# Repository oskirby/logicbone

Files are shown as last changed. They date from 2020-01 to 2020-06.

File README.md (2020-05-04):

LogicBone
=========

When you can't quite find the development board you want, why not make your own?

This project aims to design a feature rich FPGA development board that is
compatible with the open source FPGA synthesis tools such as [yosys](http://www.clifford.at/yosys/),
[NextPNR](https://github.com/YosysHQ/nextpnr) and [SymbiFlow](https://github.com/SymbiFlow),
while also targeting larger logic designs that need faster IO. The
requirements set out for this board are, in order of priority:
 * Compatiblity with open-source FPGA synthesis tools.
 * Minimum of 4Gb of high speed memory, preferably at least 8Gb.
 * At least one Ethernet interface.
 * Compatiblity with existing expansion interfaces.
 * USB interface for programming, debug and power.
 * Licenseable as Open Source Hardware.

The ultimate objective of this board is to instantiate a soft core processor, such as
the RISC-V, and use it to boot a Linux operating system with networking.

To that effect, this board is designed to be mechanically and electrically compatible
with the Beaglebone Black, but featuring a Lattice ECP5 FPGA, which is available in
logic sizes up to 85k LUTs, and a selection of hardware blocks for DDR3 DQS acceleration,
MIPI interfaces, DSPs and 3Gbps SERDES.

Features
--------

The major features of this board include:
 * Lattice ECP5 (LFE5UM5G-45F-8BG381C)
   - 44k LUTs and 351 kbits of distributed RAM 
   - 1944 kbits of embedded block RAM
   - 203 IO pins
   - 72 hardware multipliers
   - 4 PLLs
   - 2 dual channel 5Gbps SERDES
 * Beaglebone Black mechanical and header compatibility.
   - P9 is fully connected to the FPGA.
   - P8 has 32 pins connected to the FPGA.
   - 12-bit 1MSPS muxed ADC on P9 analog pins.
 * 8Gb on-board DDR3L RAM
 * KSZ9031 Gigabit Ethernet PHY
 * microSD card slot
 * USB-C upstream facing port for power and programming
 * USB-C downstream facing port with USB Superspeed support
 * M.2 E-Keyed expansion interface:
   - Accepts connectivity options in the 2230 form factor
   - Both PCIe lanes are routed to the FPGA SERDES
   - GPIO, UART, SDIO and PCM interfaces
 * MaxLinear MxL7704 power manager

Work In Progress
----------------
This project has completed the PCB layout phase, and we are moving into hardware
prototyping. While we wait for the first boards to arrive, we have a 
[schematic](logicbone.pdf) and some renders of the board that might satisfy your
curiosity.

We would be happy to accept any feedback and review on the design that you
might be willing to provide.

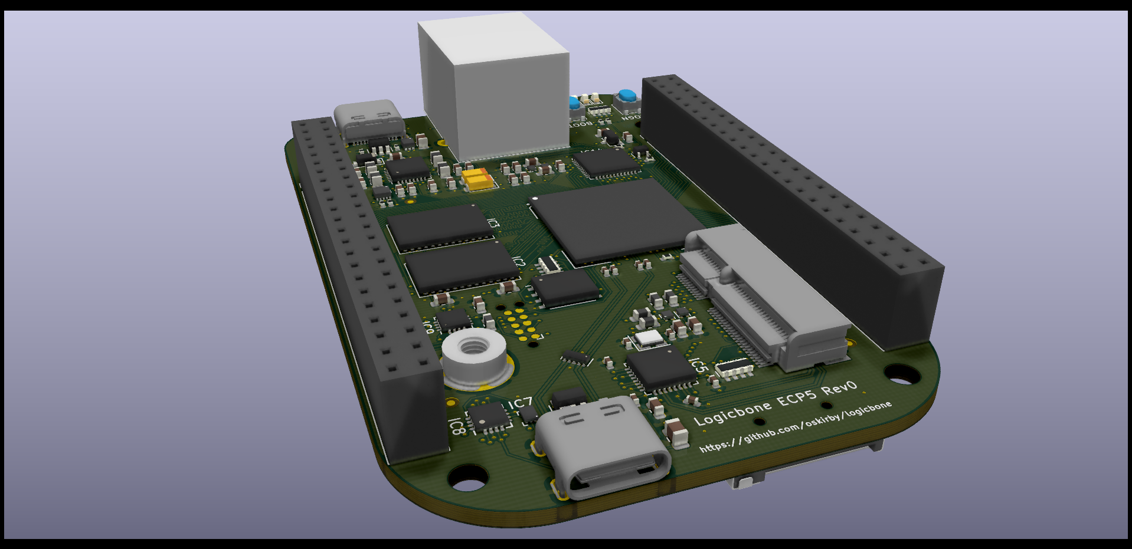
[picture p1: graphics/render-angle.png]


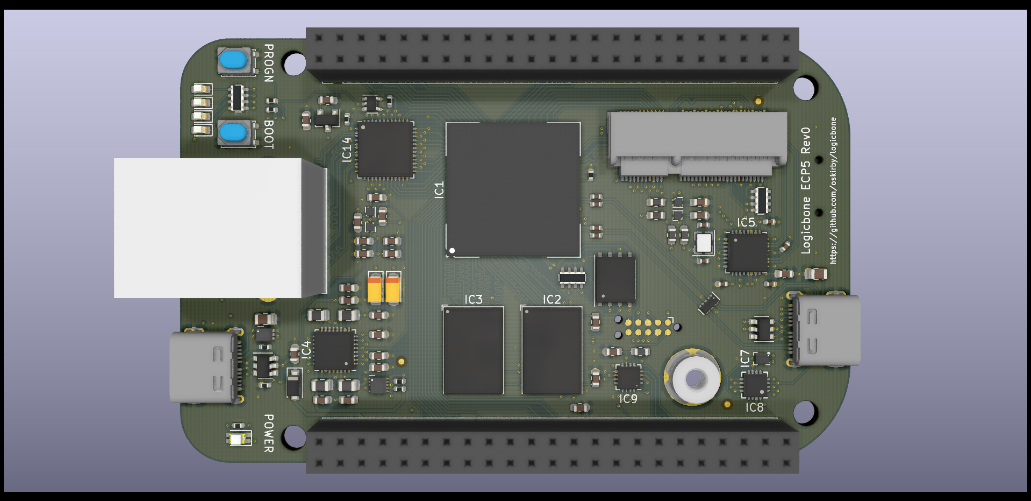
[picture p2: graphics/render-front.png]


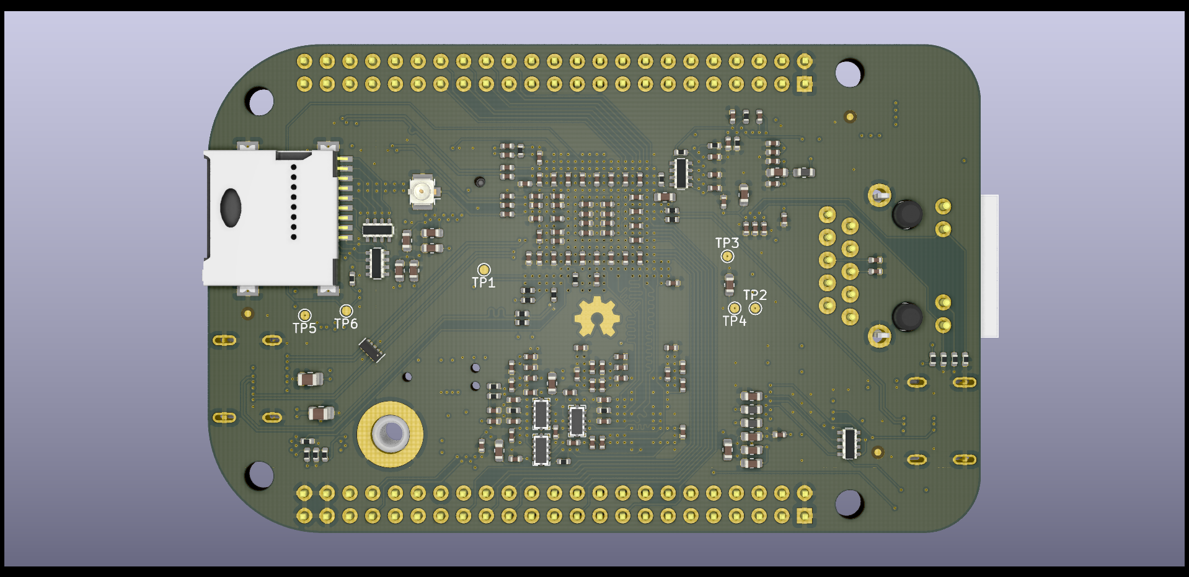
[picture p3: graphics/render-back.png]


Copyright
---------
Copyright Owen Kirby 2020

This documentation describes Open Hardware and is licensed under the
CERN OHL v1.2.

You may redistribute and modify this documentation under the terms of
the CERN OHL v1.2. (see [LICENSE.txt](LICENSE.txt)). This documentation
is distributed WITHOUT ANY EXPRESS OR IMPLIED WARRANTY, INCLUDING OF
MERCHANTABILITY, SATISFACTORY QUALITY AND FITNESS FOR A PARTICULAR
PURPOSE. Please see the CERN OHL v.1.2 for applicable conditions.

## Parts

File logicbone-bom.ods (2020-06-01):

Item | Reference(s) | Value | LibPart | Footprint | MPN Base | MPN Deluxe | Manufacturer | Qty | Order | Price | Total | Price Upg. | Total Upgr. | Link | Datasheet
1 | C101, C102, C103, C105, C106, C107, C110, C111, C112, C113, C114, C115, C116, C118, C120, C121, C122, C123, C124, C200, C201, C210, C211, C220, C221, C230, C231, C251, C257, C260, C261, C264, C265, C266, C280, C300, C301, C302, C309, C310, C311, C316, C317, C318, C319, C401, C402, C403, C411, C412, C413, C421, C422, C423, C431, C432, C433, C451, C452, C454, C455, C456, C461, C462, C463, C464, C465, C467, C469, C500, C501, C502, C503, C512, C522, C532, C542 | 100nF | Device:C_Small | Capacitor_SMD:C_0402_1005Metric | 0402YC104MAT2A |  | AVX Corporation | 77 | 1200 | $0.005 | $0.40 |  | $0.40 | https://www.digikey.com/product-detail/en/avx-corporation/0402YC104MAT2A/478-0402YC104MAT2ACT-ND/11570233 | ~
2 | C104, C117, C150, C151, C152, C153, C154, C155, C156, C157, C158, C159, C160, C161, C162, C163, C164, C165, C166, C167, C168, C169, C170, C250, C255, C303, C304, C308, C315, C400, C410, C420, C430, C440, C441, C442, C443, C445, C460, C533, C543 | 10uF | Device:C_Small | Capacitor_SMD:C_0603_1608Metric | JMK107ABJ106MA-T |  | Taiyo Yuden | 41 | 500 | $0.032 | $1.30 |  | $1.30 | https://www.digikey.com/product-detail/en/taiyo-yuden/JMK107ABJ106MA-T/587-5869-1-ND/7674989 | ~
3 | C108, C109 | 12pF | Device:C_Small | Capacitor_SMD:C_0402_1005Metric | CL05C120JB5NNNC |  | Samsung | 2 | 100 | $0.026 | $0.05 |  | $0.05 | https://www.digikey.com/product-detail/en/samsung-electro-mechanics/CL05C120JB5NNNC/1276-1178-1-ND/3889264 | ~
4 | C119, C125, C126, C127 | 4.7uF/35V | Device:C_Small | Capacitor_SMD:C_0805_2012Metric | CL21A475KLCLQNC |  | Samsung | 4 | 100 | $0.079 | $0.31 |  | $0.31 | https://www.digikey.com/product-detail/en/samsung-electro-mechanics/CL21A475KLCLQNC/1276-6722-1-ND/5961581 | ~
5 | C198, C199 | 47uF | Device:CP | Capacitor_Tantalum_SMD:CP_EIA-3216-10_Kemet-I | DNP | DNP | DNP | 2 |  |  | $0.00 |  | $0.00 |  | ~
6 | C252, C253, C258, C259, C305, C306, C307, C312, C313, C314, C404, C405, C406, C414, C415, C424, C425, C426, C434, C435, C504, C505, C506, C507, C510, C511, C520, C521, C530, C531, C540, C541 | 10nF | Device:C_Small | Capacitor_SMD:C_0402_1005Metric | ‎CL05B103KO5NNNC‎ |  | Samsung | 32 | 500 | $0.007 | $0.21 |  | $0.21 | https://www.digikey.com/product-detail/en/samsung-electro-mechanics/CL05B103KO5NNNC/1276-1051-1-ND/3889137 | ~
7 | D1 | LED_RED_GREEN | Device:LED_Dual_CACA | KiCAD_Magic:LED_0805_DUAL | IN-S85DATRG |  | Inolux | 1 | 15 | $0.291 | $0.29 |  | $0.29 | https://www.mouser.com/ProductDetail/743-IN-S85DATRG | http://www.inolux-corp.com/datasheet/SMDLED/Bi-Color%20Top%20View/IN-S85DATRG_V1.0.pdf
8 | D2, D3, D4, D5 | LED_ALT | Device:LED_ALT | LED_SMD:LED_0603_1608Metric | SML-D13M8WT86 |  | Rohm Semiconductor | 4 | 50 | $0.193 | $0.77 |  | $0.77 | https://www.mouser.com/ProductDetail/755-SML-D13M8WT86 | https://d1d2qsbl8m0m72.cloudfront.net/en/products/databook/datasheet/opto/led/chip_mono/sml-d12x8_d13x8-e.pdf
9 | D6 | SS24FL | Device:D_Schottky_ALT | Diode_SMD:D_SOD-123F | SS24FL |  | ON Semiconductor | 1 | 15 | $0.209 | $0.21 |  | $0.21 | https://www.mouser.com/ProductDetail/512-SS24FL | https://www.onsemi.com/pub/Collateral/SS26FL-D.PDF
10 | D7, D8 | D5V0F4U6SO | Logicbone:D5V0F4U6SO | Package_TO_SOT_SMD:SOT-23-6 | D5V0F4U6SO-7 |  | Diodes Incorporated | 2 | 25 | $0.264 | $0.53 |  | $0.53 | https://www.digikey.com/product-detail/en/diodes-incorporated/D5V0F4U6SO-7/D5V0F4U6SO-7DICT-ND/4457883
11 | D9, D10 | TPD4E02B04 | Logicbone:TPD4E02B04 | Package_SON:USON-10_2.5x1.0mm_P0.5mm | TPD4E02B04DQAR |  | Texas Instruments | 2 | 25 | $0.465 | $0.93 |  | $0.93 | https://www.mouser.com/ProductDetail/595-TPD4E02B04DQAR | http://www.ti.com/lit/ds/symlink/tpd4e02b04.pdf
12 | FB1, FB2, FB3, FB4, FB5, FB7, FB8, FB9 | MPZ1608S600 | Device:Ferrite_Bead_Small | Inductor_SMD:L_0603_1608Metric | MPZ1608S600ATDH5 |  | TDK | 8 | 100 | $0.039 | $0.31 |  | $0.31 | https://www.mouser.com/ProductDetail/810-MPZ1608S600ATDH5 | ~
13 | FID1, FID2, FID3, FID4, FID5, FID6 | Fiducial | Mechanical:Fiducial | Fiducial:Fiducial_0.75mm_Mask1.5mm | DNP | DNP | DNP | 6 |  |  | $0.00 |  | $0.00 |  | ~
14 | H1, H2, H3, H4 | MountingHole | Mechanical:MountingHole | MountingHole:MountingHole_3.2mm_M3 | DNP | DNP | DNP | 4 |  |  | $0.00 |  | $0.00 |  | ~
15 | H5 | 9774025360 | Mechanical:MountingHole_Pad | Logicbone:wurth-9774025360 | 9774025360R |  | Wurth | 1 | 15 | $0.907 | $0.91 |  | $0.91 | https://www.mouser.com/ProductDetail/710-9774025360R | https://www.mouser.com/datasheet/2/445/9774025360R-1728785.pdf
16 | IC1 | ECP5UM-CABGA381 | Logicbone:ECP5UM-CABGA381 | Logicbone:caBGA-381_20x20_17.0x17.0mm | LFE5UM5G-45F-8BG381C | LFE5UM5G-85F-8BG381C | Lattice Semiconductor | 1 | 12 | $31.260 | $31.26 | $54.890 | $54.89 | https://www.digikey.com/product-detail/en/lattice-semiconductor-corporation/LFE5UM5G-45F-8BG381C/220-2107-ND/6173744
17 | IC2, IC3 | DDR3-TFBGA78 | KiCAD-Magic:DDR3-TFBGA78 | Package_BGA:FBGA-78_7.5x11mm_Layout2x3x13_P0.8mm | MT41K512M8DA-107:P | AS4C1G8MD3L-12BCN | Micron | 2 | 24 | $6.409 | $12.82 | $21.082 | $42.16 | https://www.digikey.com/product-detail/en/micron-technology-inc/MT41K512M8DA-107-P/557-1764-ND/5956624 | https://www.mouser.ca/datasheet/2/671/4Gb_DDR3L-1283964.pdf
18 | IC4 | MXL7704 | Logicbone:MXL7704 | Package_DFN_QFN:QFN-32-1EP_5x5mm_P0.5mm_EP3.65x3.65mm | MxL7704-AQB-R |  | MaxLinear | 1 | 12 | $4.058 | $4.06 |  | $4.06 | https://www.digikey.com/product-detail/en/maxlinear-inc/MXL7704-AQB-R/1016-2220-1-ND/10322951 | https://www.maxlinear.com/ds/mxl7704.pdf
19 | IC5 | PI6CG18401 | Logicbone:PI6CG18401 | Package_DFN_QFN:QFN-32-1EP_5x5mm_P0.5mm_EP3.1x3.1mm | PI6CG18401ZHIEX |  | Diodes Incorporated | 1 | 12 | $2.590 | $2.59 |  | $2.59 | https://www.mouser.com/ProductDetail/729-PI6CG18401ZHIEX
20 | IC6 | NCP349 | Logicbone:NCP349 | Logicbone:DFN6_1.6x2mm | NCP349MNBK |  | ON Semiconductor | 1 | 15 | $0.682 | $0.68 |  | $0.68 | https://www.mouser.com/ProductDetail/863-NCP349MNBKTBG
21 | IC7 | FPF2595 | Logicbone:FPF2595 | Logicbone:WLCSP-12_3x4_1.3x1.8mm | FPF2595UCX |  | ON Semiconductor | 1 | 15 | $0.783 | $0.78 |  | $0.78 | https://www.mouser.com/ProductDetail/512-FPF2595UCX | https://www.onsemi.com/pub/Collateral/FPF2595-D.pdf
22 | IC8 | FUSB307 | Logicbone:FUSB307 | Package_DFN_QFN:UQFN-16-1EP_3x3mm_P0.5mm_EP1.75x1.75mm | FUSB307BMPX |  | ON Semiconductor | 1 | 15 | $1.020 | $1.02 |  | $1.02 | https://www.mouser.com/ProductDetail/863-FUSB307BMPX | https://www.onsemi.com/pub/Collateral/FUSB307B-D.PDF
23 | IC9 | TLA2518 | Logicbone:TLA2518 | Package_DFN_QFN:WQFN-16-1EP_3x3mm_P0.5mm_EP1.75x1.75mm | TLA2518IRTER |  | Texas Instruments | 1 | 12 | $3.142 | $3.14 |  | $3.14 | https://www.digikey.com/product-detail/en/texas-instruments/TLA2518IRTER/296-TLA2518IRTERCT-ND/11502569 | http://www.ti.com/lit/ds/symlink/tla2518.pdf
24 | IC10 | W25Q128 | Memory_Flash:AT25SF081-XMHF-X | Package_DFN_QFN:DFN-8-1EP_6x5mm_P1.27mm_EP4x4mm | W25Q128JVPIQ |  | Winbond | 1 | 12 | $1.342 | $1.34 |  | $1.34 | https://www.digikey.com/product-detail/en/winbond-electronics/W25Q128JVPIQ/W25Q128JVPIQ-ND/6819668 | https://www.winbond.com/resource-files/w25q128jv%20revf%2003272018%20plus.pdf
25 | IC12 | 74LVC1G07 | Logicbone:74AUC1G07 | Package_TO_SOT_SMD:SOT-353_SC-70-5 | 74LVC1G07GW,125 |  | Nexperia | 1 | 15 | $0.141 | $0.14 |  | $0.14 | https://www.mouser.com/ProductDetail/771-74LVC1G07GW-G | https://assets.nexperia.com/documents/data-sheet/74LVC1G07.pdf
26 | IC13 | TPS51206 | Logicbone:TPS51206 | Logicbone:WSON-10EP-2x2mm | TPS51206DSQR |  | Texas Instruments | 1 | 15 | $0.683 | $0.68 |  | $0.68 | https://www.mouser.com/ProductDetail/595-TPS51206DSQR | http://www.ti.com/lit/ds/symlink/tps51206.pdf
27 | IC14 | KSZ9031RNXCC | Interface_Ethernet:KSZ9031RNXCA | Package_DFN_QFN:QFN-48-1EP_7x7mm_P0.5mm_EP5.15x5.15mm | KSZ9031RNXCC |  | Microchip | 1 | 12 | $2.810 | $2.81 |  | $2.81 | https://www.digikey.com/product-detail/en/microchip-technology/KSZ9031RNXCC-TR/KSZ9031RNXCC-CT-ND/7917225 | http://ww1.microchip.com/downloads/en/DeviceDoc/00002117C.pdf
28 | IC17, IC18 | NCP110AMX110 | Logicbone:NCP110 | Package_DFN_QFN:UDFN-4-1EP_1x1mm_P0.65mm_EP0.48x0.48mm | NCP110AMX120TBG |  | ON Semiconductor | 2 | 25 | $0.270 | $0.54 |  | $0.54 | https://www.mouser.com/ProductDetail/863-NCP110AMX120TBG | https://www.onsemi.com/pub/Collateral/NCP110-D.PDF
29 | IC19, IC20 | NCP115AMX250 | Logicbone:NCP110 | Package_DFN_QFN:UDFN-4-1EP_1x1mm_P0.65mm_EP0.48x0.48mm | NCP115AMX250TCG |  | ON Semiconductor | 2 | 25 | $0.197 | $0.39 |  | $0.39 | https://www.mouser.com/ProductDetail/863-NCP115AMX250TCG | https://www.onsemi.com/pub/Collateral/NCP115-D.PDF
30 | J1 | NGFF-KEY-E | Logicbone:NGFF-KEY-E | Logicbone:TE-2199230-4 | 2199230-4 |  | TE Connectivity | 1 | 15 | $1.010 | $1.01 |  | $1.01 | https://www.mouser.com/ProductDetail/571-2199230-4
31 | J2, J5 | USB_C_Receptacle | Connector:USB_C_Receptacle | Logicbone:Molex-1054500101 | 1054500101 |  | Molex | 2 | 25 | $1.949 | $3.90 |  | $3.90 | https://www.digikey.com/product-detail/en/molex/1054500101/WM12856CT-ND/5843891 | https://www.usb.org/sites/default/files/documents/usb_type-c.zip
32 | J3 | ARJM11xx-502 | Logicbone:ARJM11xx-502 | Logicbone:ARJM11B1_502 | ARJM11B1-502-AB-ER2-T |  | Abracon | 1 | 12 | $4.752 | $4.75 |  | $4.75 | https://www.digikey.com/product-detail/en/abracon-llc/ARJM11B1-502-AB-ER2-T/535-14133-1-ND/7675242
33 | J4 | TC2050-IDC-NL | Connector_Generic:Conn_02x05_Odd_Even | Connector:Tag-Connect_TC2050-IDC-NL_2x05_P1.27mm_Vertical | TC2050-IDC-NL |  | Tag Connect | 1 |  | $0.000 | $0.00 |  | $0.00 |  | ~
34 | J6 | Micro_SD_MEM2075 | Logicbone:Micro_SD_MEM2075 | Logicbone:MEM2075 | MEM2075-00-140-01-A |  | GCT | 1 | 12 | $1.860 | $1.86 |  | $1.86 | https://www.digikey.com/product-detail/en/gct/MEM2075-00-140-01-A/2073-MEM2075-00-140-01-ACT-ND/9859685 | https://gct.co/files/drawings/mem2075.pdf
35 | J7 | u.FL | Connector:Conn_Coaxial | Connector_Coaxial:U.FL_Hirose_U.FL-R-SMT-1_Vertical | DNP | DNP | DNP | 1 |  |  | $0.00 |  | $0.00 |  | ~
36 | L1 | 2.2uH | Device:L | Inductor_SMD:L_0805_2012Metric | TFM201610ALM-2R2MTAA |  | TDK | 1 | 15 | $0.374 | $0.37 |  | $0.37 | https://www.mouser.com/ProductDetail/810-TFM2161ALM2R2MTA | ~
37 | L2, L4 | 0.47uH | Device:L | Inductor_SMD:L_0805_2012Metric | TFM201610ALM-R47MTAA |  | TDK | 2 | 25 | $0.374 | $0.75 |  | $0.75 | https://www.mouser.com/ProductDetail/810-TFM2161ALMR47MTA | https://product.tdk.com/info/en/catalog/datasheets/inductor_commercial_power_tfm201610alm_en.pdf
38 | L3 | 1uH | Device:L | Inductor_SMD:L_0805_2012Metric | MAKK2016T1R0M |  | Taiyo Yuden | 1 | 15 | $0.180 | $0.18 |  | $0.18 | https://www.mouser.com/ProductDetail/963-MAKK2016T1R0M | ~
39 | P8, P9 | BB_2x23 | Connector_Generic:Conn_02x23_Odd_Even | Connector_PinHeader_2.54mm:PinHeader_2x23_P2.54mm_Vertical | PPPC232LFBN-RC |  | Sullins Connector | 2 | 25 | $2.333 | $4.67 |  | $4.67 | https://www.digikey.com/product-detail/en/sullins-connector-solutions/PPPC232LFBN-RC/S7126-ND/810262 | ~
40 | Q1 | Q_PMOS_GSD | Device:Q_PMOS_GSD | Package_TO_SOT_SMD:SOT-23 | FDV304P |  | ON Semiconductor | 1 | 15 | $0.200 | $0.20 |  | $0.20 | https://www.mouser.com/ProductDetail/512-FDV304P | https://www.onsemi.com/pub/Collateral/FDV304P-D.PDF
41 | R1, R2, R6, R37 | 33 | Device:R | Resistor_SMD:R_0402_1005Metric | ERJ-2RKF33R0X |  | Panasonic | 4 | 100 | $0.201 | $0.80 |  | $0.80 | https://www.digikey.com/product-detail/en/panasonic-electronic-components/ERJ-2RKF33R0X/P33-0LCT-ND/1746675 | ~
42 | R3, R4, R10, R27, R28 | 240 | Device:R | Resistor_SMD:R_0402_1005Metric | ERJ-2RKF2400X |  | Panasonic | 5 | 100 | $0.021 | $0.11 |  | $0.11 | https://www.mouser.com/ProductDetail/667-ERJ-2RKF2400X | ~
43 | R5, R39 | 100 | Device:R_Small | Resistor_SMD:R_0402_1005Metric | ERJ-2RKF1000X |  | Panasonic | 2 | 100 | $0.017 | $0.03 |  | $0.03 | https://www.mouser.com/ProductDetail/667-ERJ-2RKF1000X | ~
44 | R7 | 12.1k | Device:R_Small | Resistor_SMD:R_0402_1005Metric | ERJ-2RKF1212X |  | Panasonic | 1 | 100 | $0.015 | $0.02 |  | $0.02 | https://www.mouser.com/ProductDetail/667-ERJ-2RKF1212X | ~
46 | R11, R12, R18, R32 | 5.1k | Device:R | Resistor_SMD:R_0402_1005Metric | ERJ-2RKF5101X |  | Panasonic | 4 | 100 | $0.017 | $0.07 |  | $0.07 | https://www.mouser.com/ProductDetail/667-ERJ-2RKF5101X | ~
47 | R8, R13, R19, R20, R21, R22, R23, R24, R25, R29, R30, R31, R35 | 10k | Device:R | Resistor_SMD:R_0402_1005Metric | ERJ-2RKF1002X |  | Panasonic | 13 | 200 | $0.016 | $0.21 |  | $0.21 | https://www.mouser.com/ProductDetail/667-ERJ-2RKF1002X | ~
48 | R14, R15, R16, R38 | 47 | Device:R | Resistor_SMD:R_0402_1005Metric | ERJ-2RKF47R0X |  | Panasonic | 4 | 100 | $0.017 | $0.07 |  | $0.07 | https://www.mouser.com/ProductDetail/667-ERJ-2RKF47R0X | ~
49 | R17, R26 | 1.5k | Device:R | Resistor_SMD:R_0402_1005Metric | ERJ-2RKF1501X |  | Panasonic | 2 | 100 | $0.006 | $0.01 |  | $0.01 | https://www.digikey.com/product-detail/en/panasonic-electronic-components/ERJ-2RKF1501X/P1-50KLCT-ND/194105 | ~
50 | R33 | 750 | Device:R | Resistor_SMD:R_0402_1005Metric | ERJ-2RKF7500X |  | Panasonic | 1 | 100 | $0.018 | $0.02 |  | $0.02 | https://www.mouser.com/ProductDetail/667-ERJ-2RKF7500X | ~
51 | R34, R36 | 1.2k | Device:R | Resistor_SMD:R_0402_1005Metric | ERJ-2RKF1201X |  | Panasonic | 2 | 100 | $0.016 | $0.03 |  | $0.03 | https://www.mouser.com/ProductDetail/667-ERJ-2RKF1201X | ~
53 | RN1, RN2, RN3 | 47 | Device:R_Network08 | KiCAD_Magic:EXBD-1206 | EXB-D10C470J |  | Panasonic | 3 | 100 | $0.163 | $0.49 |  | $0.49 | https://www.mouser.com/ProductDetail/667-EXB-D10C470J | http://www.vishay.com/docs/31509/csc.pdf
54 | RN4, RN5, RN6, RN7, RN8, RN11 | 10k | Device:R_Pack04 | Resistor_SMD:R_Array_Concave_4x0603 | CAT16-103J4GLF |  | Bourns | 6 | 100 | $0.014 | $0.08 |  | $0.08 | https://www.mouser.com/ProductDetail/652-CAT16-103J4GLF | ~
55 | RN9 | 470 | Device:R_Pack04 | Resistor_SMD:R_Array_Concave_4x0603 | CAT16-471J4LF |  | Bourns | 1 | 100 | $0.092 | $0.09 |  | $0.09 | https://www.mouser.com/ProductDetail/652-CAT16-471J4LF | ~
56 | SW1, SW2 | SW_SPST | Switch:SW_SPST | Button_Switch_SMD:SW_SPST_PTS810 | PTS810 SJK 250 SMTR LFS |  | C&K Switches | 2 | 25 | $0.165 | $0.33 |  | $0.33 | https://www.mouser.com/ProductDetail/611-PTS810SJK250SMTR | https://dznh3ojzb2azq.cloudfront.net/products/Tactile/PTS810/documents/datasheet.pdf
57 | Y1 | 25MHz | Logicbone:Crystal_GND24 | Crystal:Crystal_SMD_2520-4Pin_2.5x2.0mm | ECS-250-18-36B-CKY-TR |  | ECS Inc. | 1 | 15 | $0.363 | $0.36 |  | $0.36 | https://www.mouser.com/ProductDetail/520-250-18-36B-CKYT | https://ecsxtal.com/store/pdf/ECX-2236B.pdf
 |  |  |  |  |  |  |  |  |  | Total: | $88.90 | Total Upgr: | $141.87

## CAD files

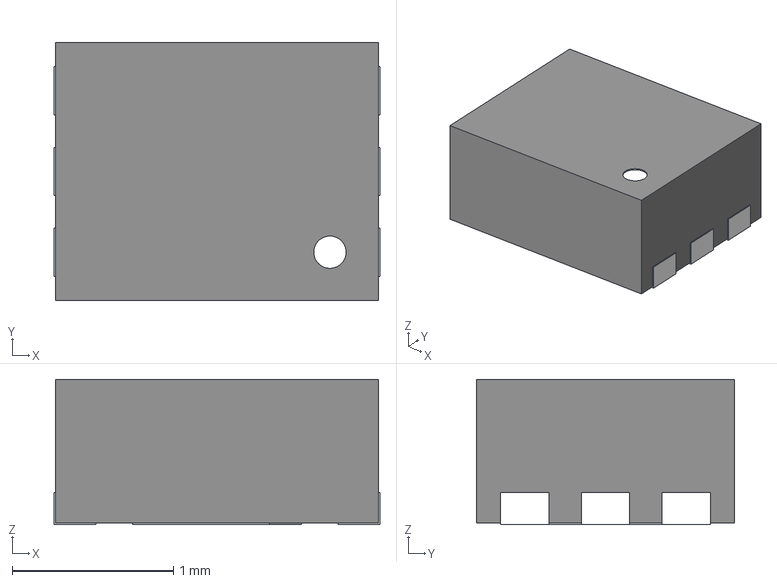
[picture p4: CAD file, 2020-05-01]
package3d/dfn6-2x1.6mm.step
2.02 x 1.60 x 0.9 mm

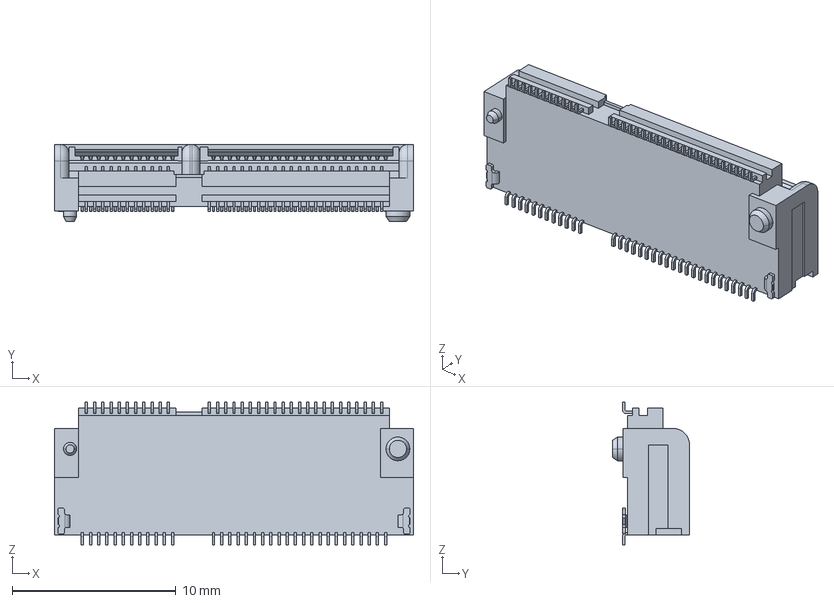
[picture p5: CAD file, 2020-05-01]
package3d/c-2199230-4-b2-3d.stp
21.9 x 4.70 x 8.70 mm

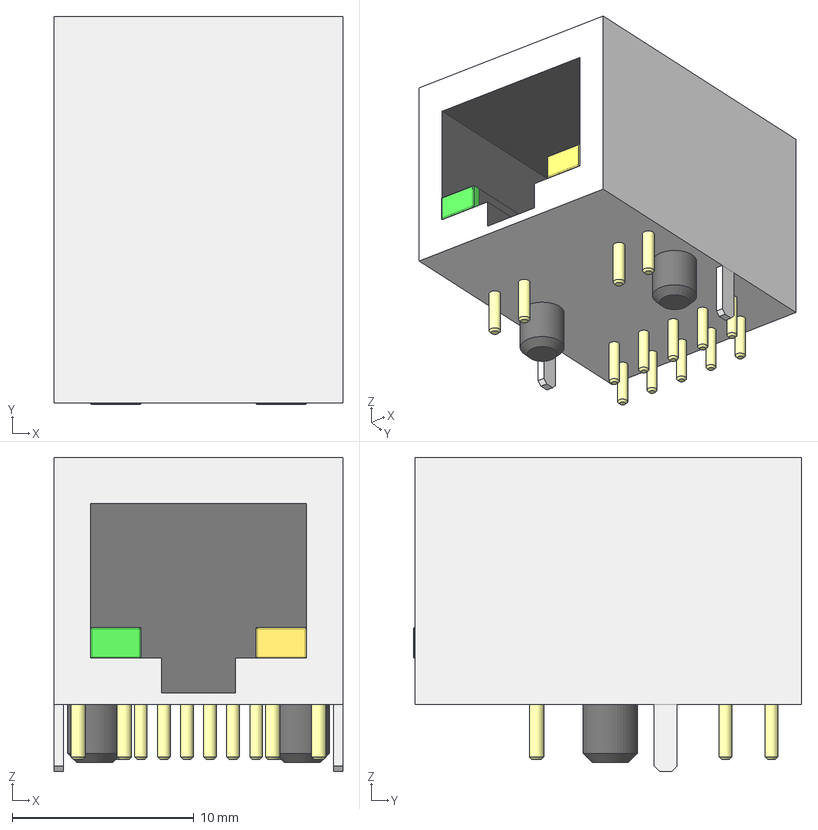
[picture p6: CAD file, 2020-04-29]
package3d/arjm11b1-502.step
15.9 x 21.4 x 17.3 mm

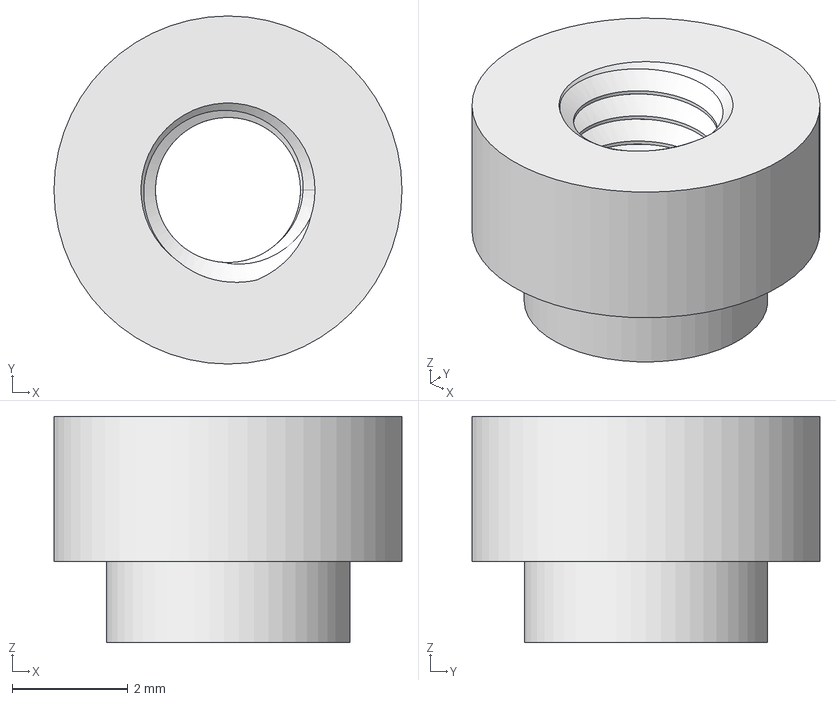
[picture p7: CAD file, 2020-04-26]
package3d/wurth-9774025360.step
6.00 x 6.00 x 3.90 mm

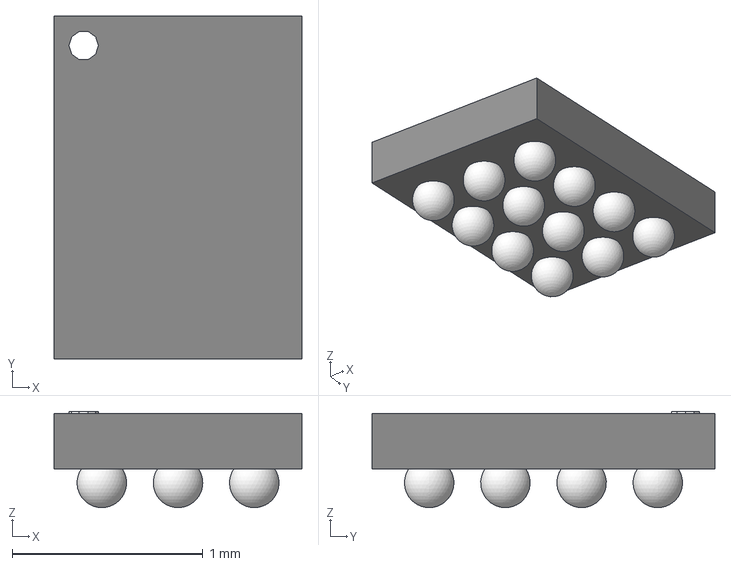
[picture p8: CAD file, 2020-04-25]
package3d/wlcsp12-p04mm.step
1.30 x 1.80 x 0.505 mm

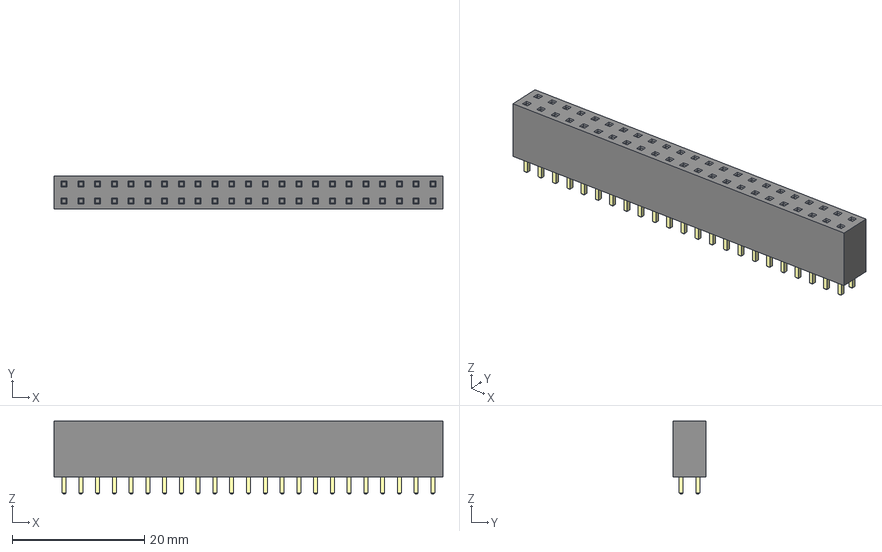
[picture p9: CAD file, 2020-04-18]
package3d/bb-pin-header-2x23.step
58.9 x 5.00 x 11.1 mm

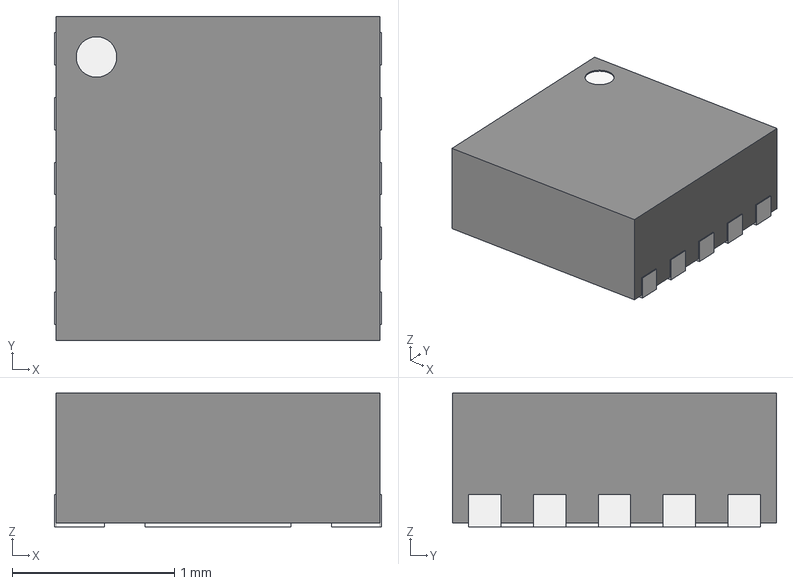
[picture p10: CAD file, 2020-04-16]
package3d/WSON10-2x2mm-EP.step
2.02 x 2.00 x 0.825 mm

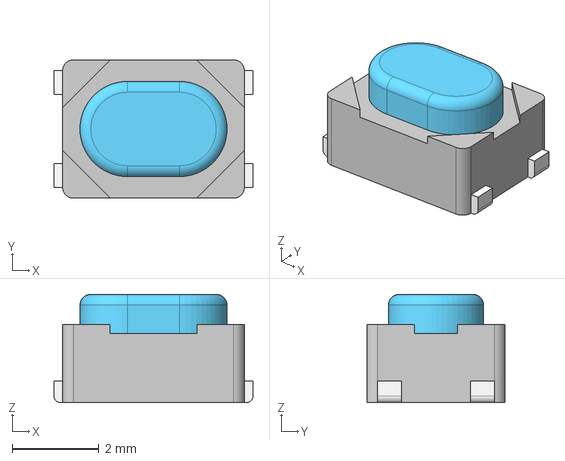
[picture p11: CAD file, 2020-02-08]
package3d/PTS810.step
4.60 x 3.20 x 2.50 mm

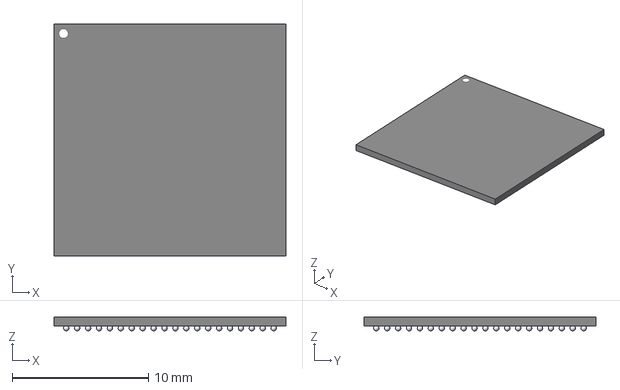
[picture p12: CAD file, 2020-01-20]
package3d/cabga-381-ecp5.step
17.0 x 17.0 x 1.01 mm

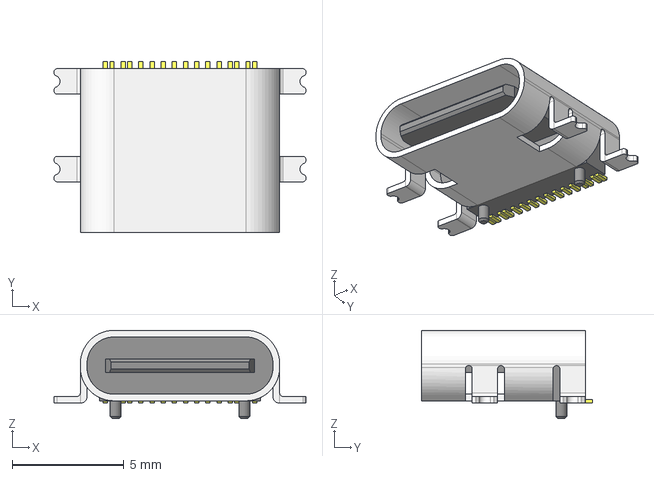
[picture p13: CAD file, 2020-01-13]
package3d/usb4110.step
11.3 x 7.68 x 3.96 mm

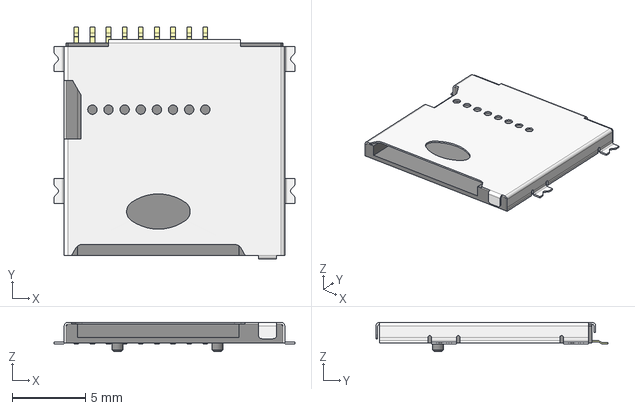
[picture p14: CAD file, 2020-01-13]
package3d/microsd-mem2075.step
16.4 x 15.8 x 2.00 mm

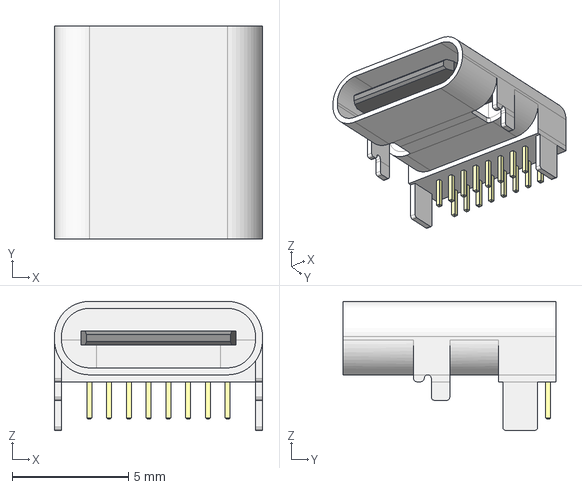
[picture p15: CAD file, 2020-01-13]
package3d/usb4085.step
8.95 x 9.17 x 5.56 mm

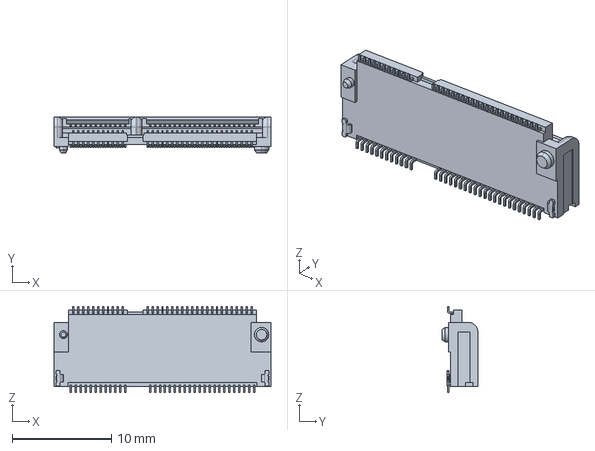
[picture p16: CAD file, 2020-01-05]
package3d/c-2199119-4-c-3d.stp
21.9 x 3.62 x 8.70 mm

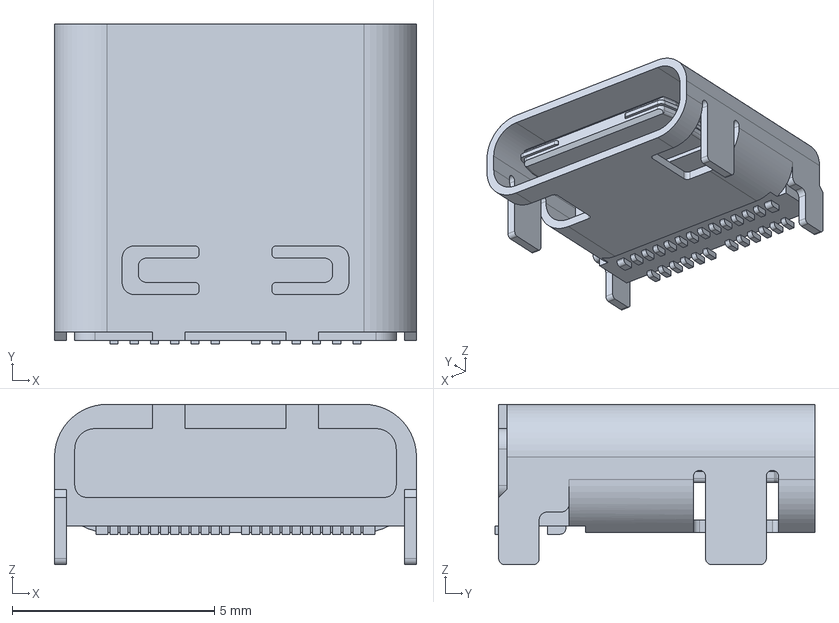
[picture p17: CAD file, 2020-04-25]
package3d/1054500101.stp
8.94 x 7.90 x 3.96 mm

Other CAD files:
package3d/arjm11b1-502.fcstd
package3d/bb-pin-header-2x23.FCStd
package3d/microsd-mem2075.fcstd
package3d/usb4085.fcstd
package3d/usb4110.fcstd

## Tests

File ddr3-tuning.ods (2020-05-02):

 | Inner Speed | Outer Speed
 | 6.7972 | 5.54599 | ps/mm
Net | Inner1 | Outer1 | Time1 | Error1 | Inner2 | Outer2 | Time2 | Error2
DDR3_CLK | 22.043 | 0 | 149.8306796 | 0 | 10.494 | 0 | 221.1604964 | 0
DDR3_A0 | 20.581 | 0 | 139.8931732 | -9.93750639999999 | 10.765 | 0 | 213.0650312 | -8.09546519999998
DDR3_A1 | 19.318 | 0 | 131.3083096 | -18.52237 | 10.197 | 0.8 | 205.05615 | -16.1043464
DDR3_A2 | 19.318 | 0 | 131.3083096 | -18.52237 | 11.57 | 1.6 | 218.8254976 | -2.33499879999999
DDR3_A3 | 22.145 | 0 | 150.523994 | 0.693314399999991 | 0 | 10.197 | 207.07645403 | -14.08404237
DDR3_A4 | 21.718 | 0 | 147.6215896 | -2.20909 | 12.577 | 0 | 233.109974 | 11.9494776
DDR3_A5 | 22.347 | 0 | 151.8970284 | 2.06634880000001 | 12.696 | 0 | 238.1942796 | 17.0337832
DDR3_A6 | 0 | 25.003 | 138.66638797 | -11.16429163 | 9.963 | 0 | 206.38689157 | -14.77360483
DDR3_A7 | 22.625 | 0 | 153.78665 | 3.95597040000001 | 0 | 12.694 | 224.18744706 | 3.02695066000001
DDR3_A8 | 24.333 | 0 | 165.3962676 | 15.565588 | 0 | 11.386 | 228.54290974 | 7.38241333999997
DDR3_A9 | 23.533 | 0 | 159.9585076 | 10.127828 | 11.04 | 0 | 234.9995956 | 13.8390992
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

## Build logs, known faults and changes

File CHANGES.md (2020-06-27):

# Logicbone ECP5 Changelog

All notable changes to the project will be documented in this file.

## Logicbone - Unreleased Changes
 - Annotated schematic with required bodges for board bringup.

## Logicbone - rev0-prototype - 2020-06-01
 - Initial release of rev0 prototype design.

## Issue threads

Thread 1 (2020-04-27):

Validate ECP5 pinout

oskirby, 2020-04-27:
The caBGA381 is a big package, with a lot of balls. That's a lot of data entry that is ripe for user error and we should take some time to review the pinout to make sure its correct before manufacturing begins.

We also need to pay attention to compatibility between logic sizes, and the ECP5-5G variants to get an idea of which parts can be substituted.

oskirby, 2020-04-30:
It seems that the ECP5 and ECP5-5G versions are interchangeable with one another, with a few tweaks to voltage programming (1.2V core and SERDES instead of 1.1V).

On the 45F logic sizes, pads K16 and K17 are no-connect, and fortunately we are not using them for anything on this design (they were sacrificed to make room for more bypass caps).

TLDR: This design is compatible with both the ECP5 and ECP5-5G in either the 45F or 85F logic sizes.

Closed 2020-04-29.

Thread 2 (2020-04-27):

Create BOM

oskirby, 2020-04-27:
Chase down supplier links for everything on the board to make sure nothing has magically gone out of stock and to get some estimates on pricing.

oskirby, 2020-05-03:
Closed in commit b731f665e2e0ec511eb55cc5416a246310af917d

There are three possible variants of builds that I am considering, depending on how much memory and logic are available. For the prototype run, I only plan on building the base and deluxe versions.

FPGA                  | Memory | Price Change | Description
-----------------------|-------------|--------------------|---------------
LFE5UM-45F      | 512MB   |                        | Base model
LFE5UM5G-45F | 1GB       |  +10$              | USBSS and PCIe 2.0 capable
LFE5UM5G-85F | 2GB       | +60$               | Deluxe model

oskirby, 2020-05-04:
After thinking about it a bit more, it seems silly not to just use the ECP5-5G for all builds, it only adds about $5 when compared to the non-5G part in the same logic size. I have gone and tweaked the BOM accordingly to make the LFE5UM5G-45F and 1GB of DDR3 as the base model.

See: 2c916801f092d31ea59eb32323762b132f2a3a1c

Closed 2020-05-03.

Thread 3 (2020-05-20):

Bad part choices (prototype run)

oskirby, 2020-05-20:
This issue is mostly just to keep a list of parts that we might want to change out if we get a chance.

| Designators | Part                 |  Issue
|------------------|--------------------|----------
| IC7 | FPF2595         | 0.4mm pitch CSP package is a little too fine. Our stencil manufacturer has raised concerns about yield.
| L4, L2 | 0805 Inductor | High current inductors for VCORE and VDDR are a little hard to source in this size. Suggest using a larger footprint to increase options and reduce cost.
| RN1, RN2, RN3 | EXB-D10C470J | Panasonic seems to be the only vendor for this particular footprint, which might lead to supply issues for future production runs. The 2x5 pin rectangular arrangement seems to be more common.

oskirby, 2020-06-04:
Another comment from the CM is that the XDFN regulators are a pain in the butt, and should be substituted with a larger and less ambiguous part (such as a TSOP-5).

oskirby, 2020-06-19:
While we're at it, the PGOOD LED (D1) is way too bright and we should increase its inline resistance (R10). To avoid adding another line item to the BOM, the next value of resistance to try would be 750 ohm.

oskirby, 2020-06-20:
After a quick bodge, it seems that 750ohm leave the green LED in D1 too bright,  but the red LED is about right. I think the whole circuit around D1 should be rethought either into discrete LEDs, or to add another resistor tune the drive strength of red and green separately.

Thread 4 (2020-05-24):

P8 eMMC pinouts are incorrect

oskirby, 2020-05-24:
It seems that there is an discrepancy in the Beaglebone Black reference manual, and the schematic. The SRM states that P8 pins 11 through 21 are used for the eMMC and shouldn't be used by the capes when the eMMC is in use, but the Beaglebone schematics show P8 pins 3-6 and 20-25 are used by the eMMC.

Unfortunately, the Logicbone was laid out according to the reference manual, which means that we won't be compatible with capes that make use of P8 pins 11-21 such as the CRAMPS board or 24-bit LCD displays.

oskirby, 2020-05-24:
For the record, I was working with the BBB_SRM revision A5.2 dated April 11th, 2013

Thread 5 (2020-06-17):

PMIC 5VSYS pin is a power input (not output)

oskirby, 2020-06-17:
The MxL7704 datasheet leaves the purpose of the 5VSYS pin a bit ambiguous as to whether it is internally connected to VIN, or whether it's requires an external RC filter to VIN. Turns out it needs an external RC filter. We can work around it on the prototypes by bodging a 10ohm resistor between 5VSYS and VBUS, but this should be fixed for future production runs.

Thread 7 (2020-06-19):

ECP5 has no means to reset itself

oskirby, 2020-06-19:
It seems that there are three ways in which the ECP5 can reset itself in order to handle multi-boot images:
- VCC, VCCAUX and VCCIO8 rise above their POR thresholds.
- Rising edge on PROGRAMN pin
- Issuing a REFRESH command over SPI slave or JTAG ports.

I was hoping that one of the config ports would have been accessible internally from the FPGA fabric to issue the REFRESH command, but this doesn't appear to be the case so instead we'll need to bodge the board so that the FPGA can pull the PROGRAMN pin.

On the prototypes, we will work around the issue by removing IC12 and bridging ETH_RESET to SYS_RESET. This will allow the ETH_RESET pin to reboot the FPGA, but we loose the ability to reset the ethernet PHY independently of the rest of the system.

A better solution would be to pull SYS_RESET low via one of the unused pins in the DDR3 bank.

oskirby, 2020-07-26:
For the DFU bootloader, it has been requested to add some non-volatile state that can allow the user image to boot into the DFU image without needing to physically press the boot pin. Without such a state, the DFU bootloader has no way to distinguish between a normal power-on and when rebooting back into the DFU bootloader.

oskirby, 2020-07-27:
I think my favourite solution so far to the non-volatile "goto DFU" problem is to use a small IO expander such as the PCA9570 to control the pull-up on the boot button. At a true power-on reset, the PCA9570 would initialize to a pull-up state but when pulled low before a soft reset, the bootloader would detect this as a "goto DFU" reboot.

bmentink, 2022-07-13:
Any solution to this?

oskirby, 2022-07-13:
@bmentink for the ECP5 in general, the common solution is to connect the `PROGRAMn` pin to any GPIO of the FPGA, which gives the logic fabric the ability to pull `PROGRAMn` and trigger a reset of the FPGA. This works just fine, but it makes the boot process somewhat inflexible when there are multiple bitstreams to navigate.

For the Logicibone, my prototype board have been modified to reuse the reset line on the ethernet controller to achieve this behavior (this is noted on page 4 of the schematic). A permanent fix will require another board revision to provide a dedicated reset line. I don't have any plans to produce another board revision for the foreseeable future due to the chip shortage and a general lack of time to work on this project.

bmentink, 2022-07-13:
@oskirby
Many thanks for the reply. I was asking as I am trying to port your bootloader to the Colorlight i5 board as per:
[((https://github.com/oskirby/tinydfu-bootloader/issues/5))]

With the resetn GPIO line connected to PROGRAMN, how do you select which image to boot to ... (bootloader or user)?

Cheers,

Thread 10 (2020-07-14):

Finish testing prototype hardware

oskirby, 2020-07-14:
The list of things yet to be tested on the prototype boards before we should start looking into the next revision

- [ ] Micro-SD card slot.
- [ ] Downstream-Facing USB port detection and power management.
- [ ] Downstream-Facing USB port SERDES support (test out https://github.com/enjoy-digital/usb3_pipe)
- [ ] Analog-to-Digital converter.
- [ ] m.2 PCIe SERDES support.
- [ ] Gather noise and current measurements for VCORE and VDDR supplies.
- [ ] LiteX support for 2GB memory size.

oskirby, 2020-07-14:
So far the microSD card seems to work in SPI mode, and I have been to boot from it using the LiteX BIOS. I have thus far been unsuccessful in getting Linux to detect the cards. The full-width microSD card support in Litex still seems like a work in progress.

oskirby, 2020-07-14:
A new commit to the bootloader (https://github.com/oskirby/tinydfu-bootloader/commit/1e0b711ec6c7751dd92b2645906e17b54229aafb) should now enable the DFP port power.

oskirby, 2020-07-19:
I've added a test to verify that the ADC works as expected (https://github.com/oskirby/logicbone-tests/commit/b8254bc7a177077abc939152cf0f3d3648f6a925)

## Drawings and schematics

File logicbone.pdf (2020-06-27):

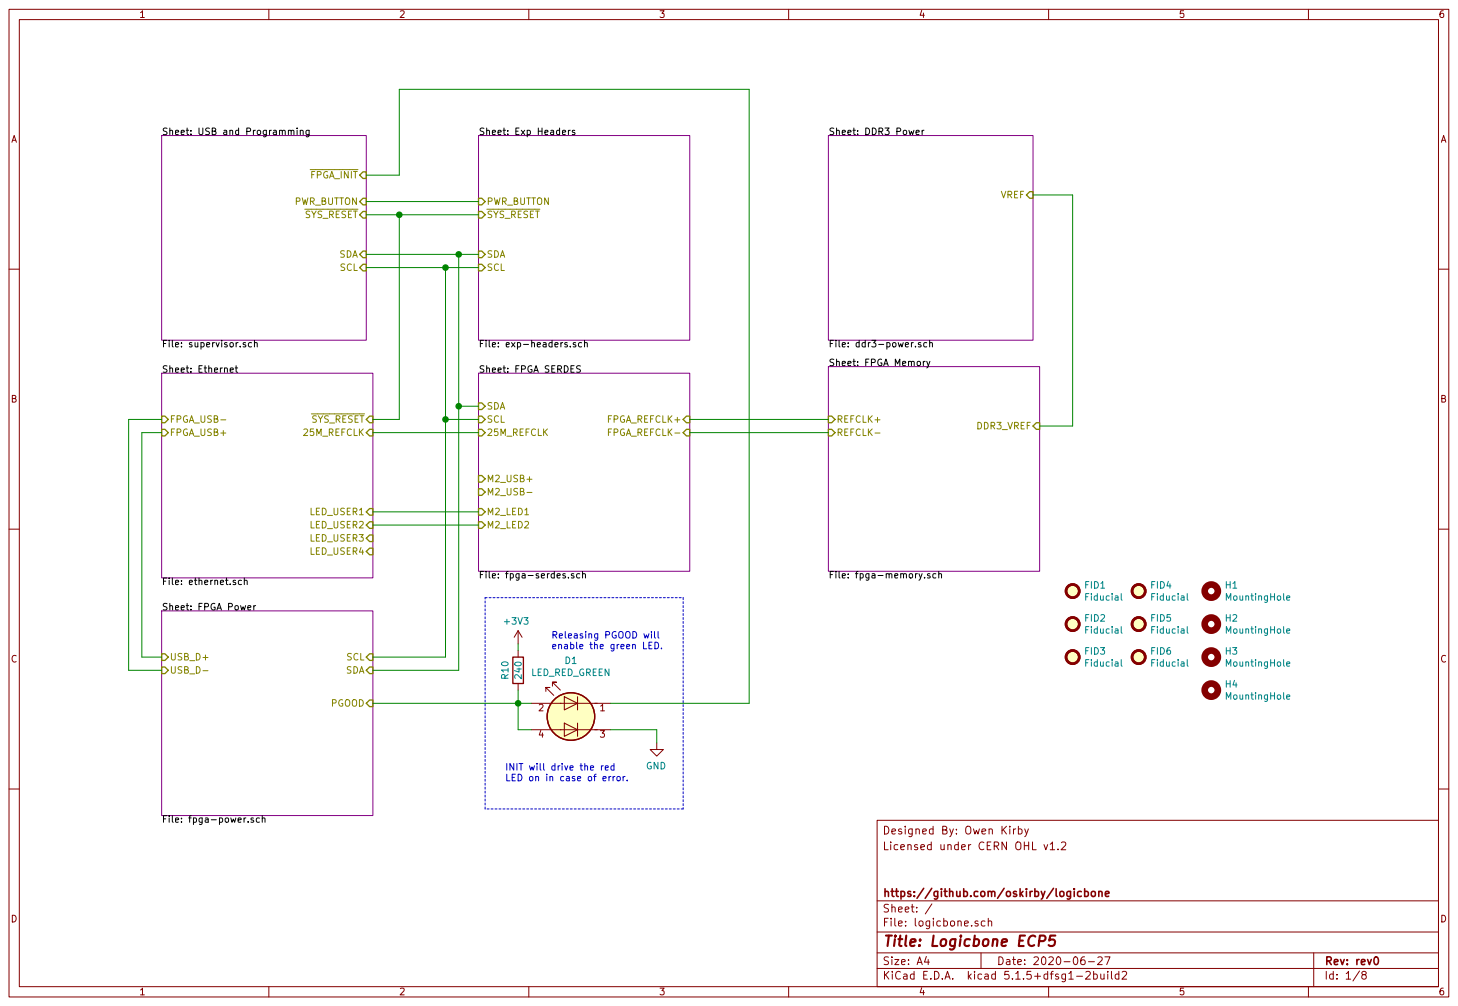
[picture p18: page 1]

FPGA_REFCLK+ FPGA_REFCLK- M2_USB+ M2_USB- M2_LED1 M2_LED2 Sheet: USB and Programming

File: exp-headers.sch SYS_RESET PWR_BUTTON

File: fpga-serdes.sch

FID4 Fiducial FID5 Fiducial FID6 Fiducial FID3 Fiducial FID1 Fiducial Releasing PGOOD will

enable the green LED.
LED_RED_GREEN

INIT will drive the red
LED on in case of error.

Licensed under CERN OHL v1.2 Designed By: Owen Kirby

File: logicbone.sch Sheet: / https://github.com/oskirby/logicbone

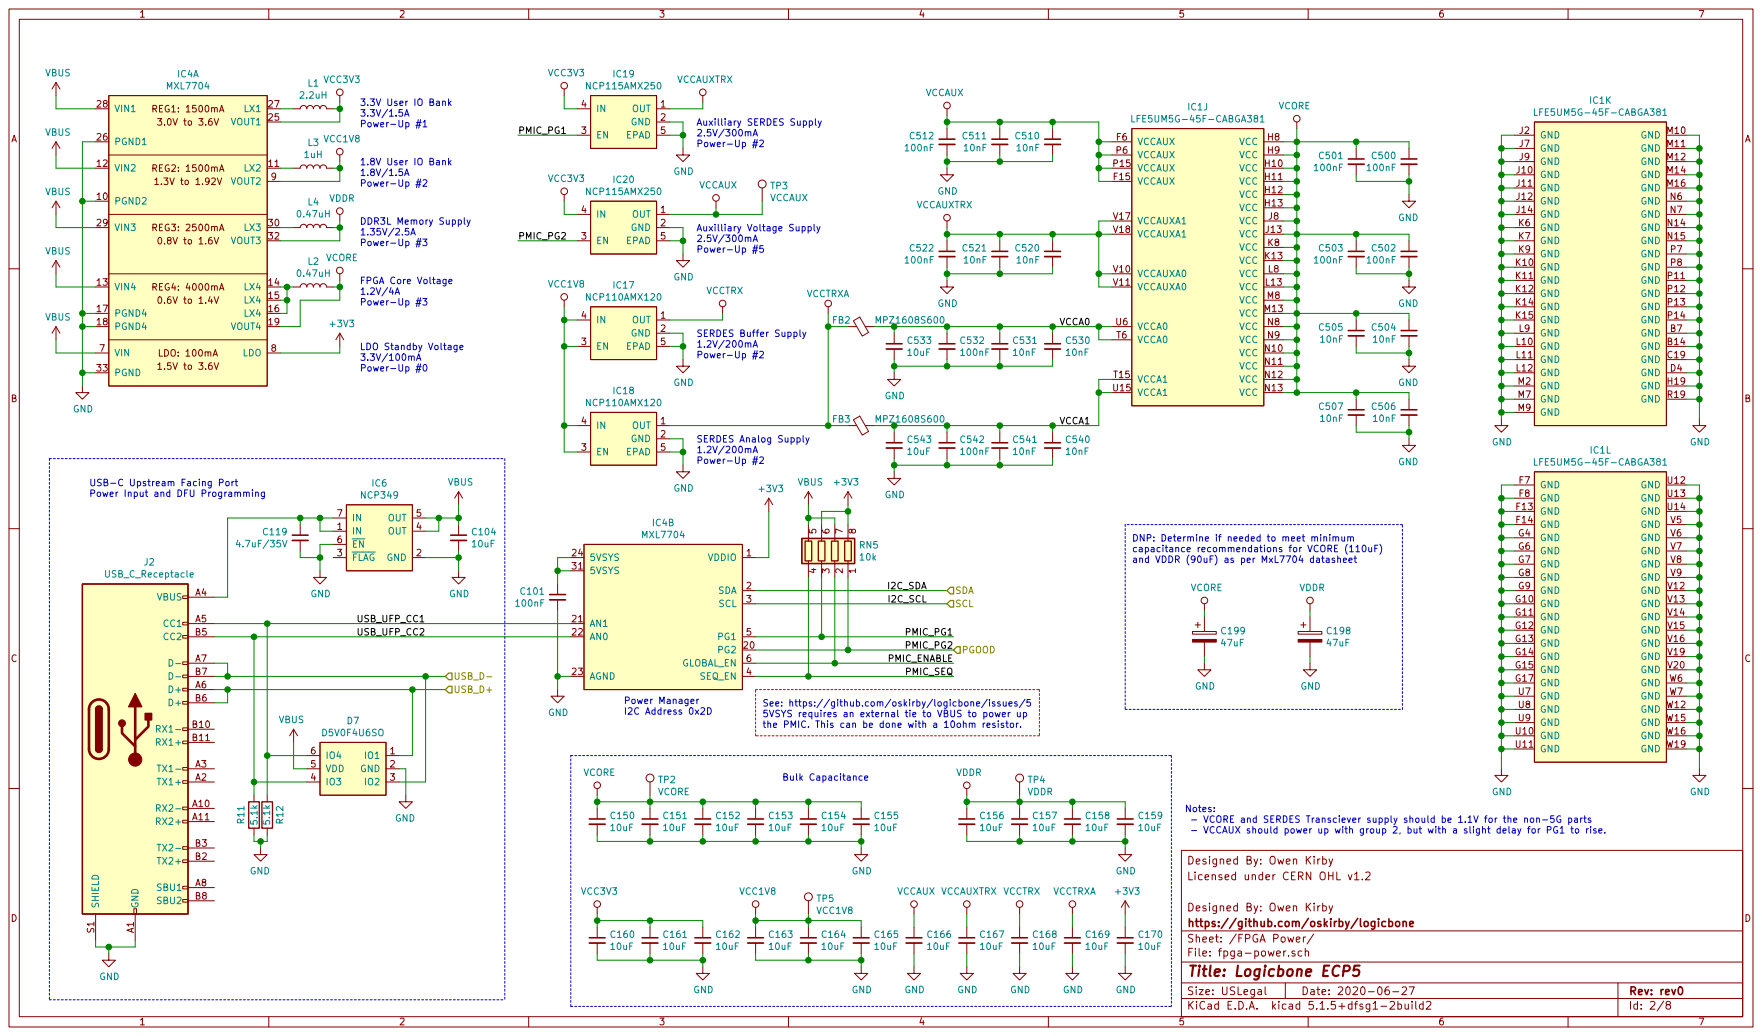
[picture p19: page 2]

the PMIC. This can be done with a 10ohm resistor. USB-C Upstream Facing Port

capacitance recommendations for VCORE (110uF)
and VDDR (90uF) as per MxL7704 datasheet

See: https://github.com/oskirby/logicbone/issues/5
5VSYS requires an external tie to VBUS to power up

- VCORE and SERDES Transciever supply should be 1.1V for the non-5G parts
- VCCAUX should power up with group 2, but with a slight delay for PG1 to rise.

D Date: 2020-06-27 KiCad E.D.A. kicad 5.1.5+dfsg1-2build2
File: fpga-power.sch Sheet: /FPGA Power/ https://github.com/oskirby/logicbone

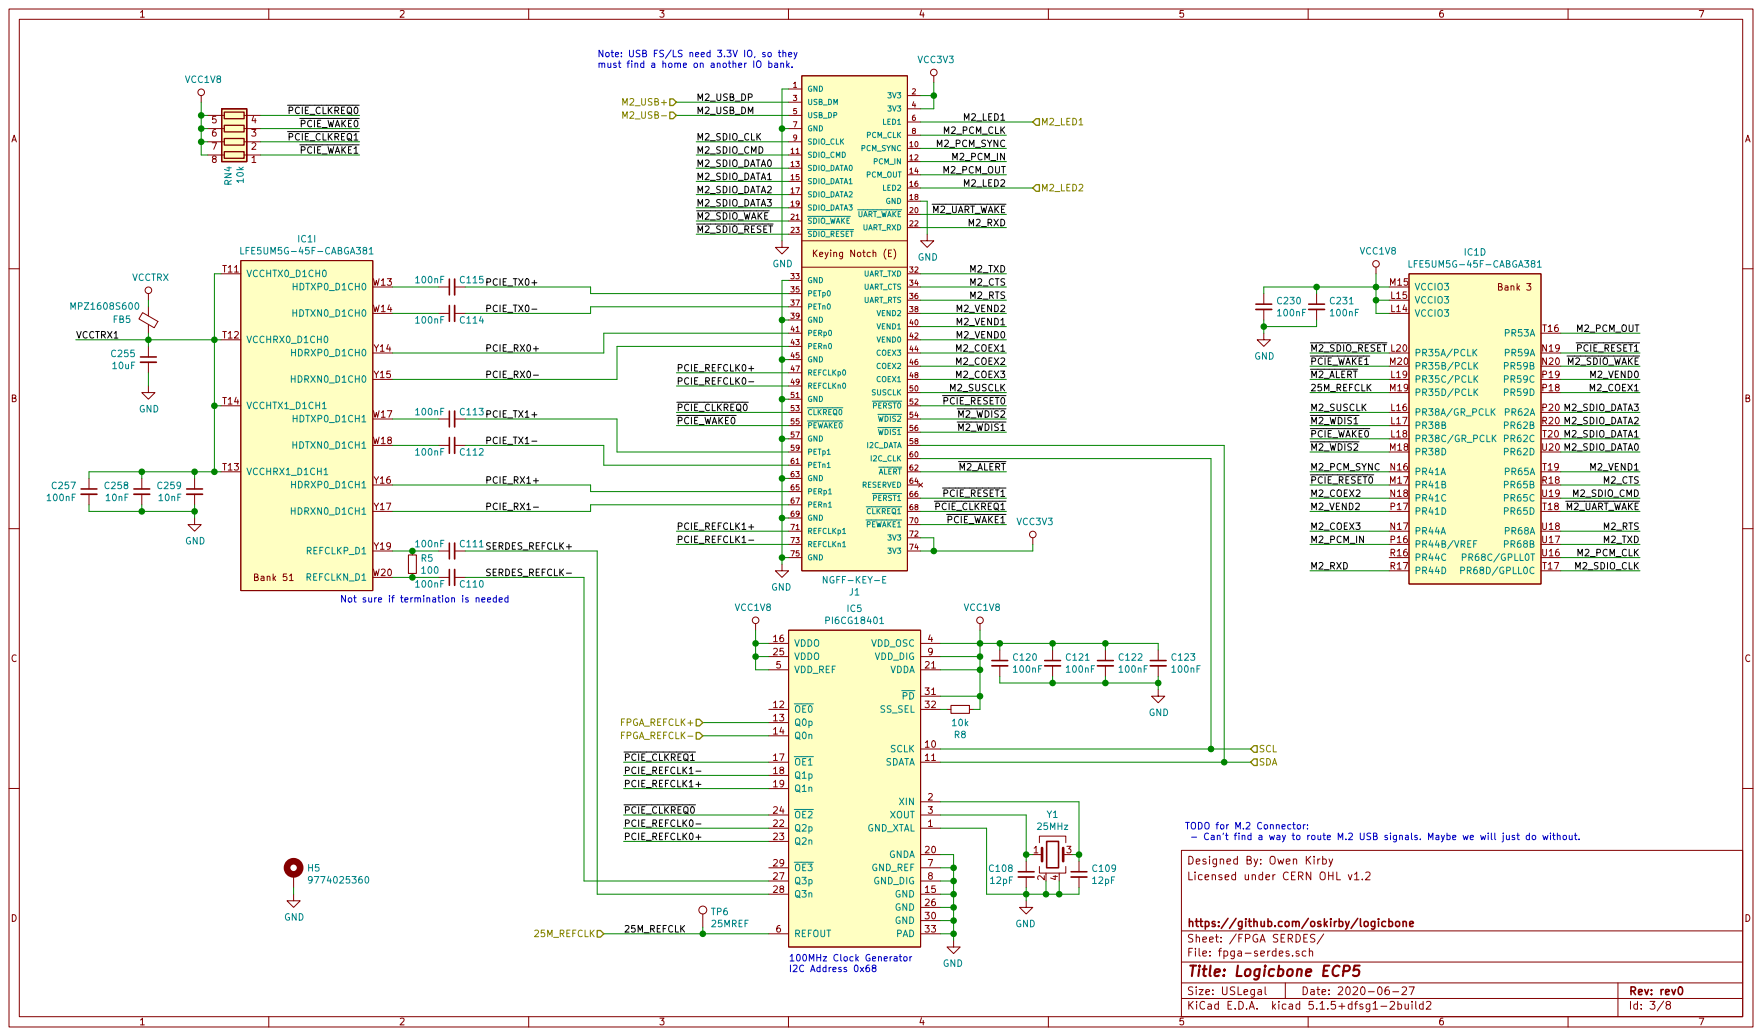
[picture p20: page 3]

Note: USB FS/LS need 3.3V IO, so they must find a home on another IO bank.
PCIE_WAKE1 PCIE_RESET1 PCIE_RESET0 M2_UART_WAKE

Licensed under CERN OHL v1.2 Designed By: Owen Kirby C123

- Can't find a way to route M.2 USB signals. Maybe we will just do without.

D Date: 2020-06-27 KiCad E.D.A. kicad 5.1.5+dfsg1-2build2
File: fpga-serdes.sch Sheet: /FPGA SERDES/ https://github.com/oskirby/logicbone

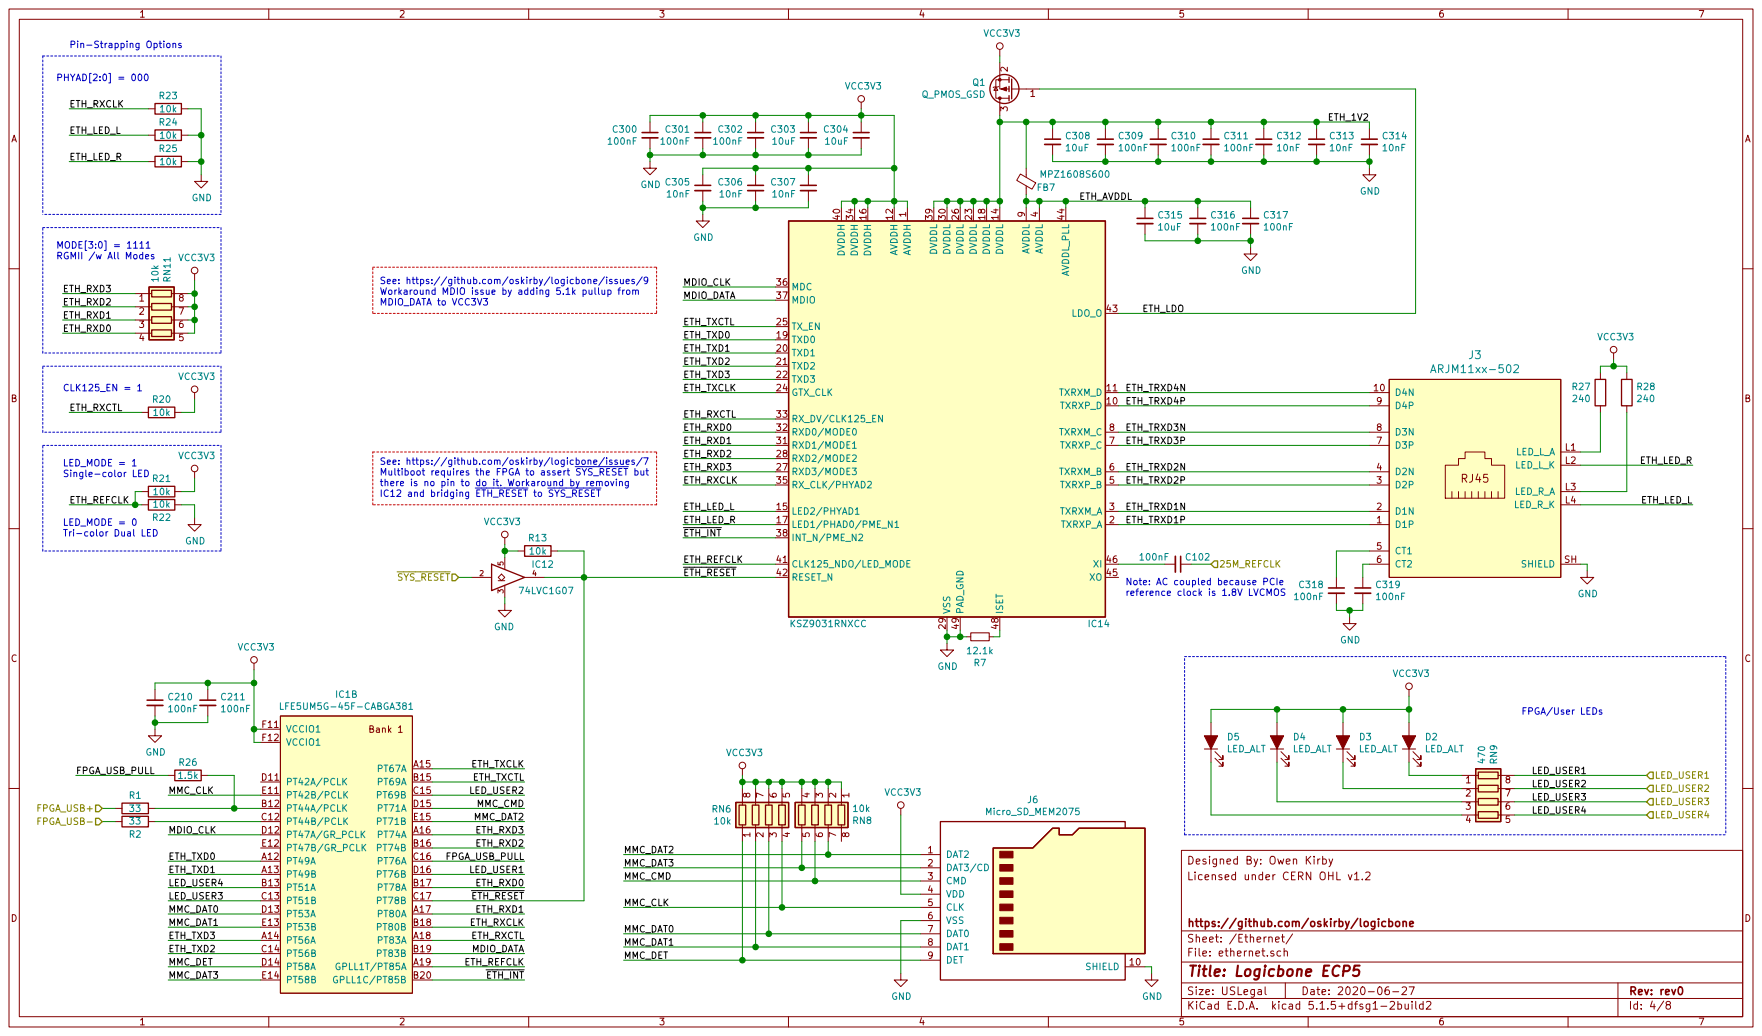
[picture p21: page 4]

See: https://github.com/oskirby/logicbone/issues/9
Workaround MDIO issue by adding 5.1k pullup from

Multiboot requires the FPGA to assert SYS_RESET but
there is no pin to do it. Workaround by removing
IC12 and bridging ETH_RESET to SYS_RESET

LED_MODE = 0 Tri-color Dual LED

Note: AC coupled because PCIe
reference clock is 1.8V LVCMOS

Licensed under CERN OHL v1.2 Designed By: Owen Kirby

D Date: 2020-06-27 KiCad E.D.A. kicad 5.1.5+dfsg1-2build2
File: ethernet.sch Sheet: /Ethernet/ https://github.com/oskirby/logicbone

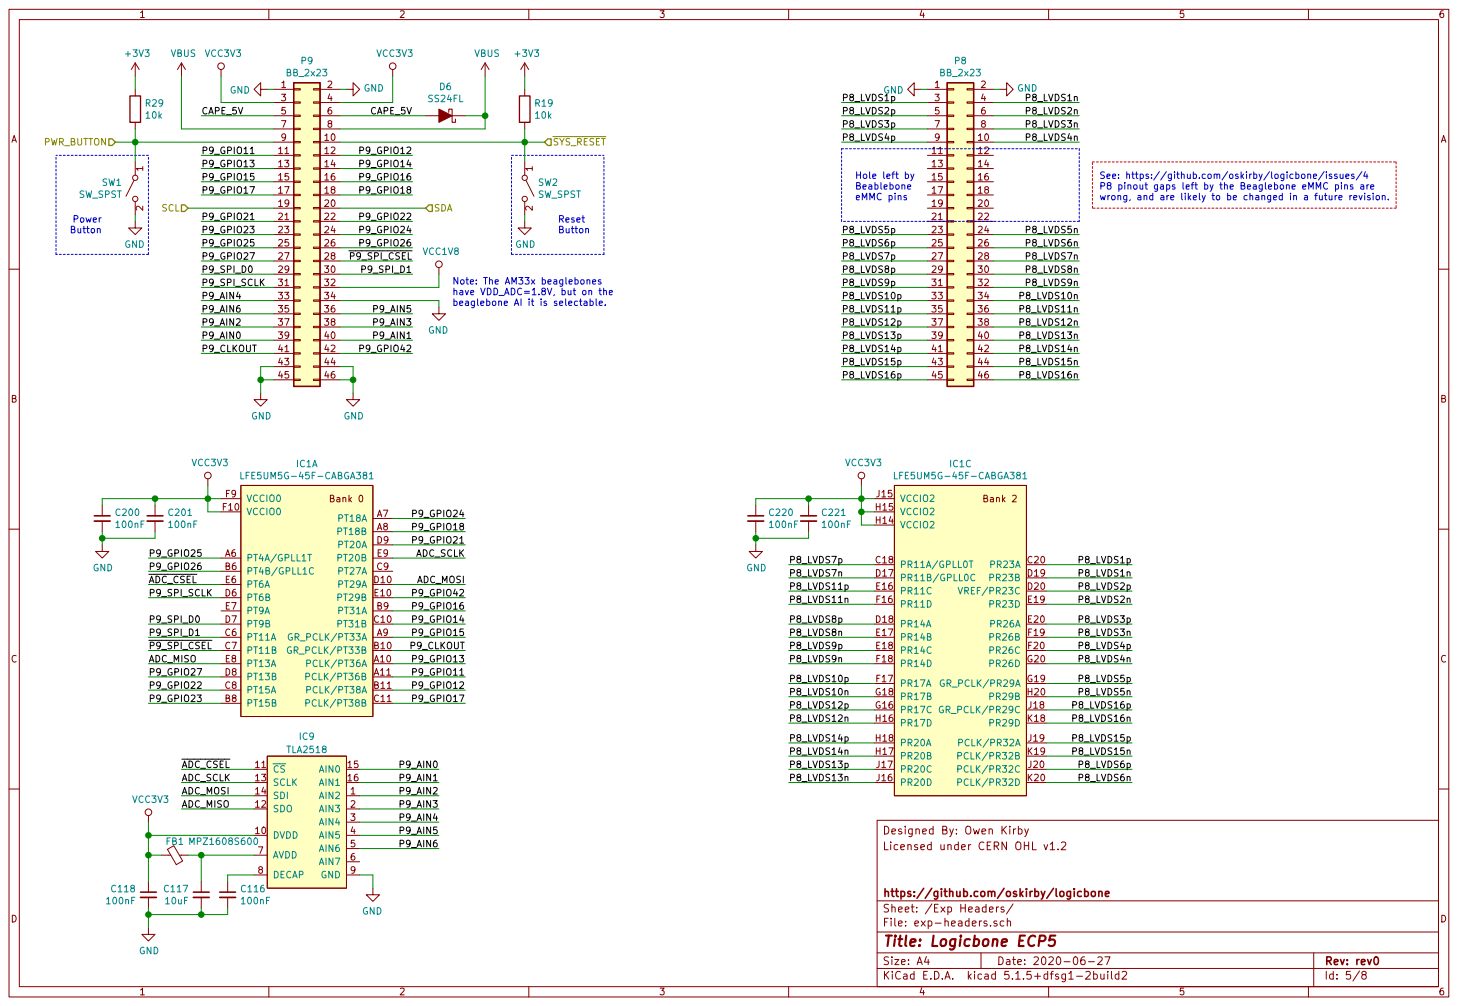
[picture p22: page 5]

See: https://github.com/oskirby/logicbone/issues/4
P8 pinout gaps left by the Beaglebone eMMC pins are
wrong, and are likely to be changed in a future revision.

Note: The AM33x beaglebones have VDD_ADC=1.8V, but on the

beaglebone AI it is selectable.

Licensed under CERN OHL v1.2 Designed By: Owen Kirby GND

https://github.com/oskirby/logicbone
Sheet: /Exp Headers/
File: exp-headers.sch
Id: 5/8 Title: Logicbone ECP5

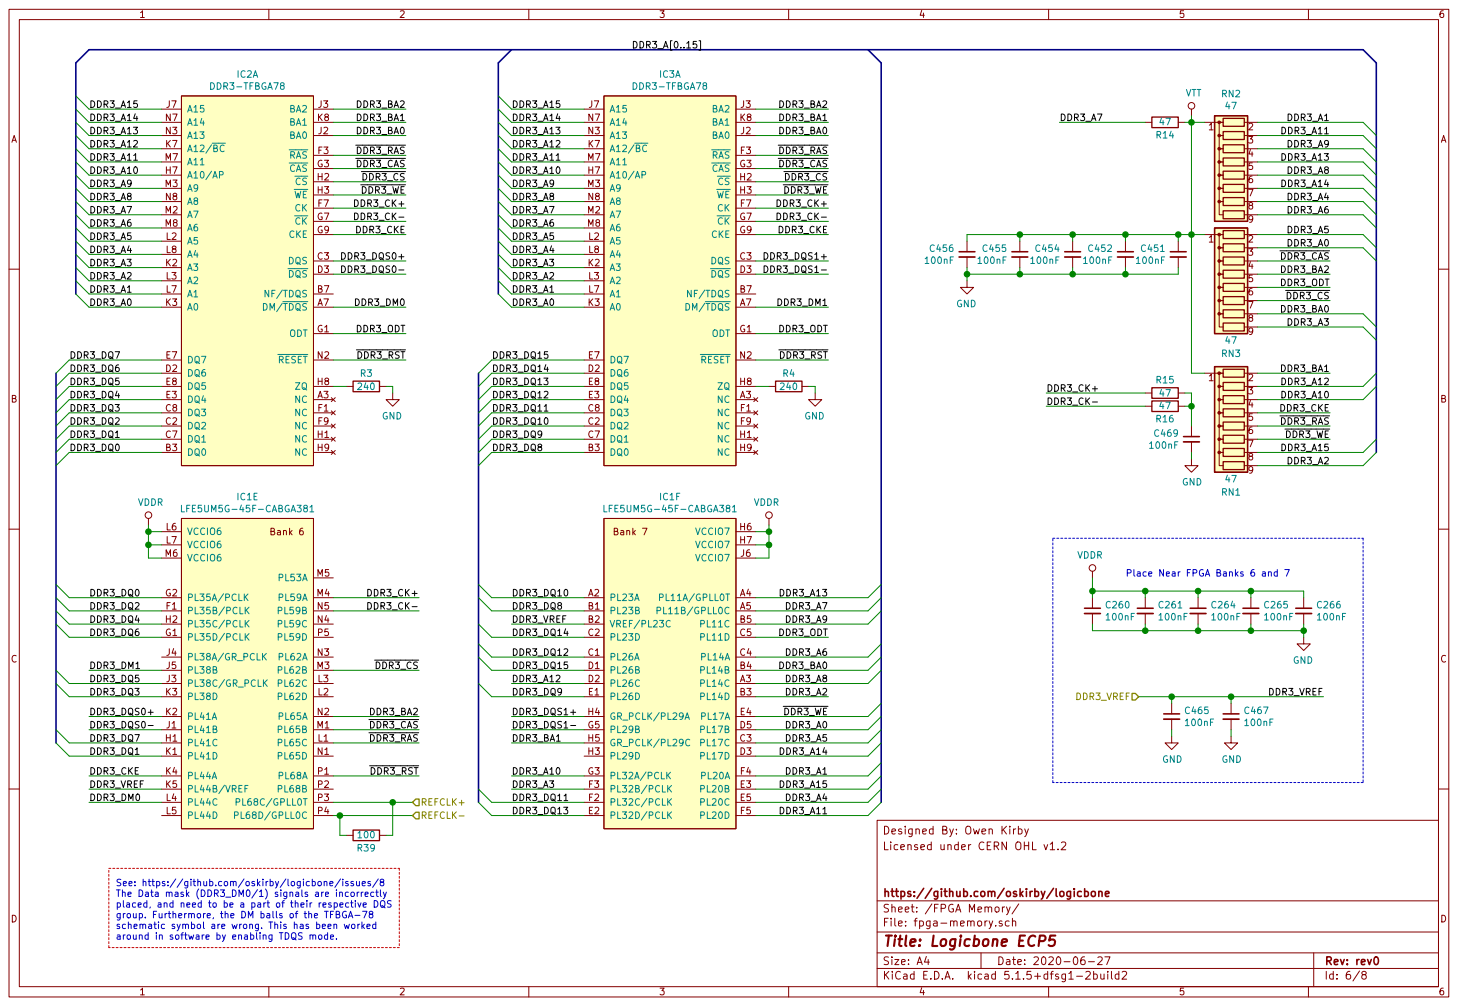
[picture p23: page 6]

Licensed under CERN OHL v1.2 Designed By: Owen Kirby GND

https://github.com/oskirby/logicbone
Sheet: /FPGA Memory/
File: fpga-memory.sch
Id: 6/8 Title: Logicbone ECP5

The Data mask (DDR3_DM0/1) signals are incorrectly
placed, and need to be a part of their respective DQS
group. Furthermore, the DM balls of the TFBGA-78
schematic symbol are wrong. This has been worked
around in software by enabling TDQS mode.

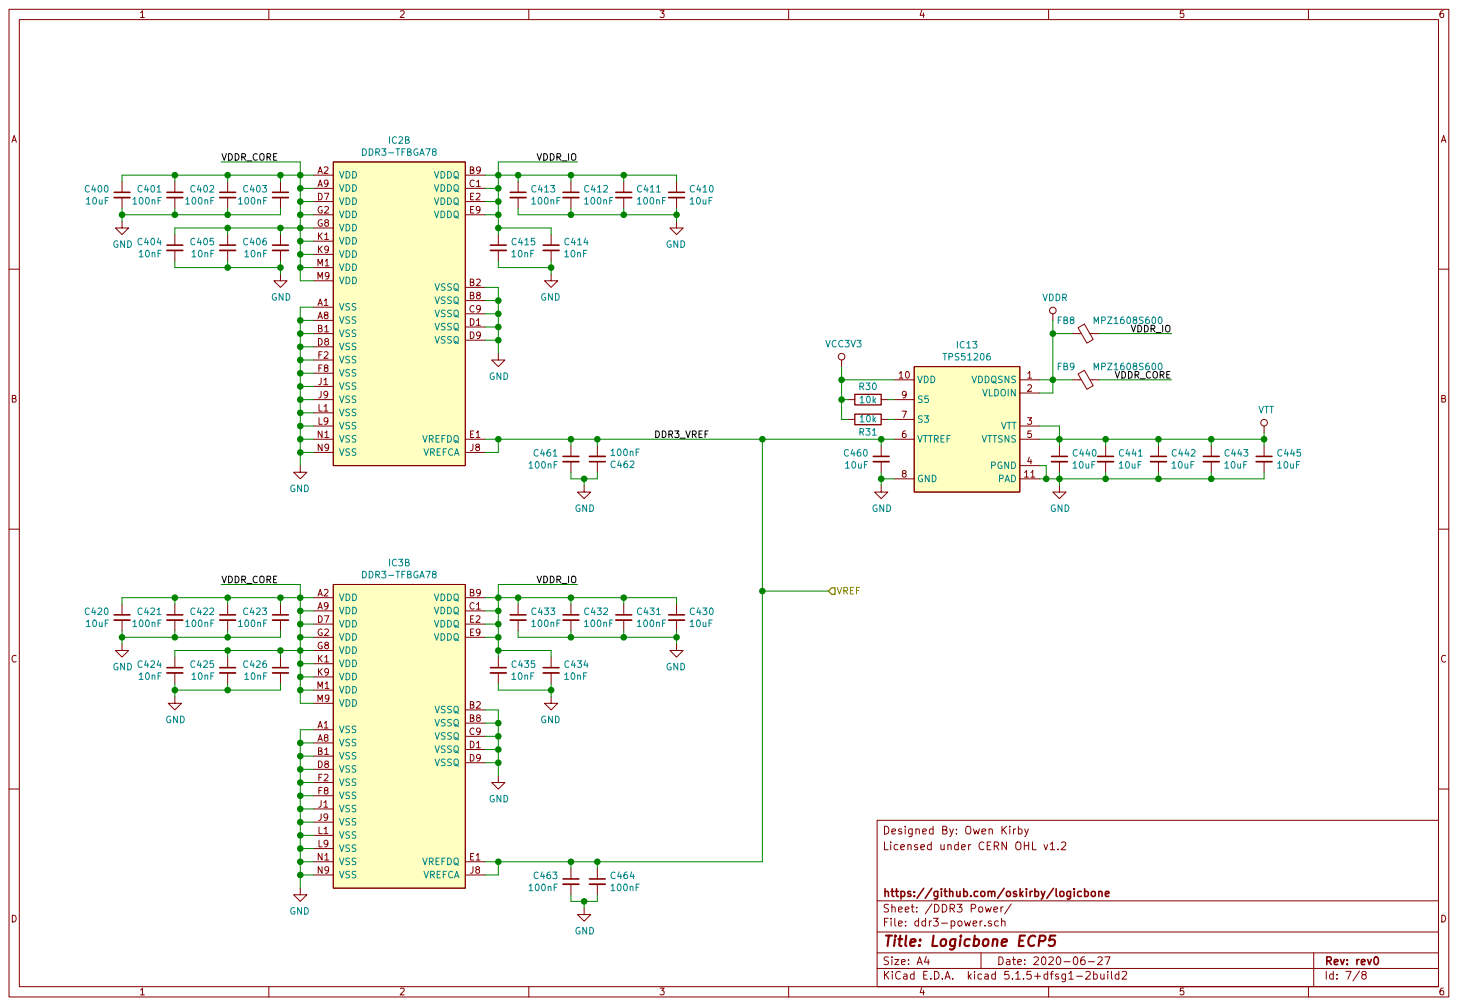
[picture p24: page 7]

100nF GND GND
Licensed under CERN OHL v1.2 Designed By: Owen Kirby R31

File: ddr3-power.sch Sheet: /DDR3 Power/ https://github.com/oskirby/logicbone

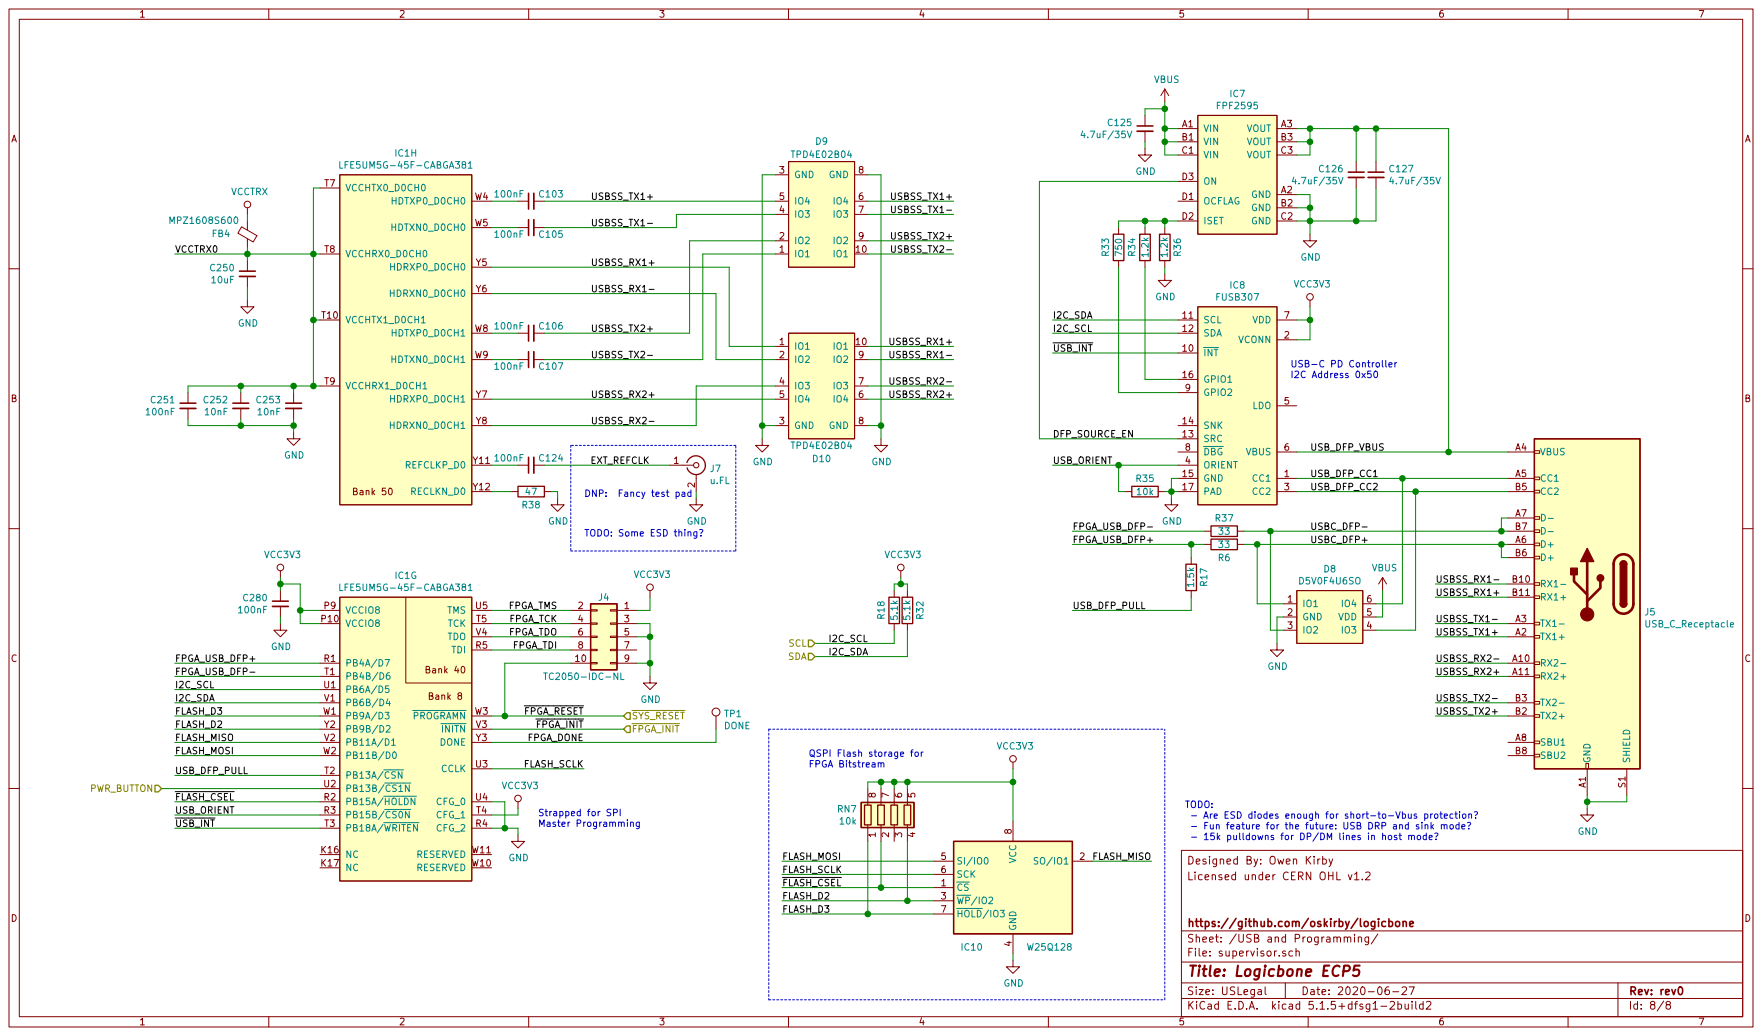
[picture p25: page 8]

DNP: Fancy test pad

VBUS

FPGA_TDI FPGA_TMS FPGA_TCK 4 | 3

Licensed under CERN OHL v1.2 Designed By: Owen Kirby VCC3V3

- Are ESD diodes enough for short-to-Vbus protection?
- Fun feature for the future: USB DRP and sink mode?
- 15k pulldowns for DP/DM lines in host mode?

4 SI/IO0 5 SCK 6 HOLD/IO3 7 VCC

D Date: 2020-06-27 KiCad E.D.A. kicad 5.1.5+dfsg1-2build2
https://github.com/oskirby/logicbone
Sheet: /USB and Programming/
File: supervisor.sch
Id: 8/8 Title: Logicbone ECP5

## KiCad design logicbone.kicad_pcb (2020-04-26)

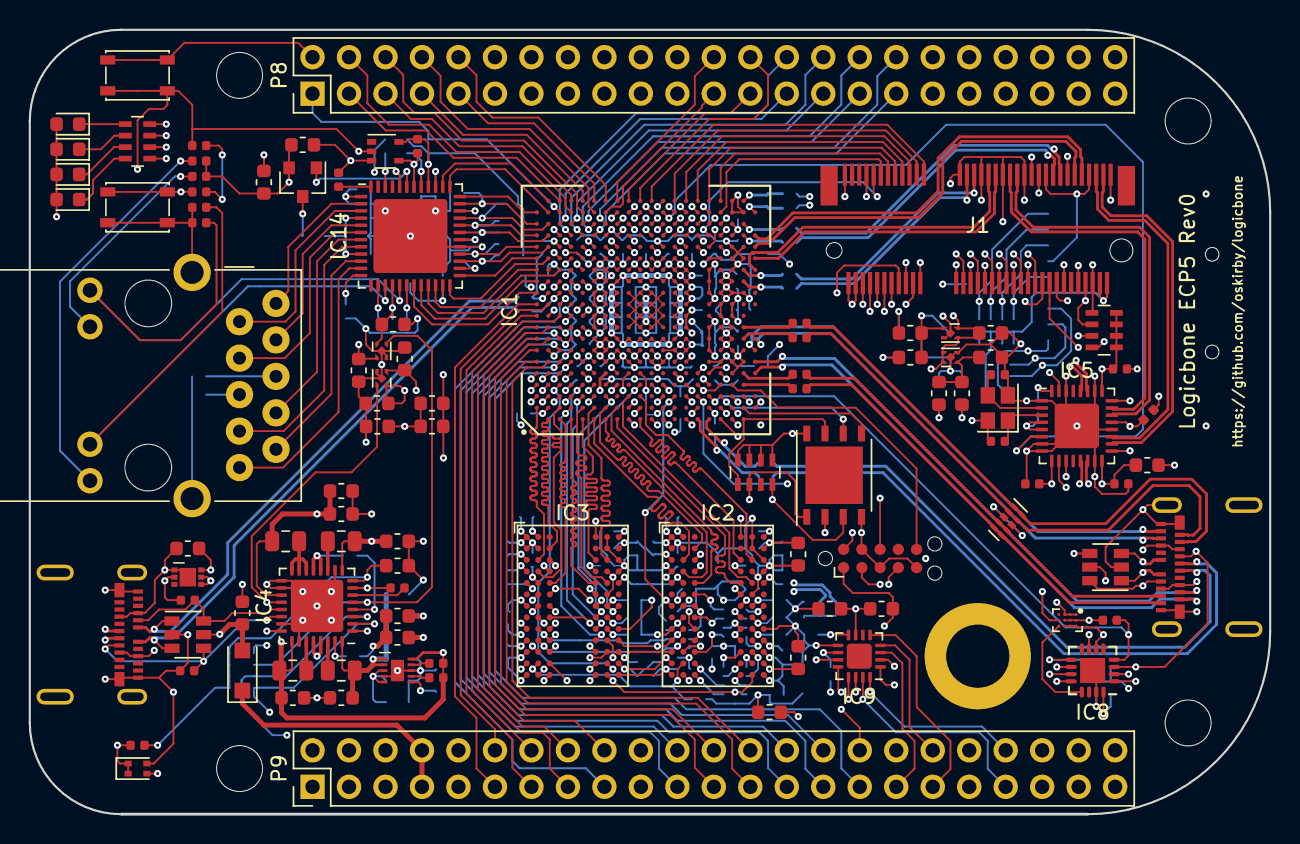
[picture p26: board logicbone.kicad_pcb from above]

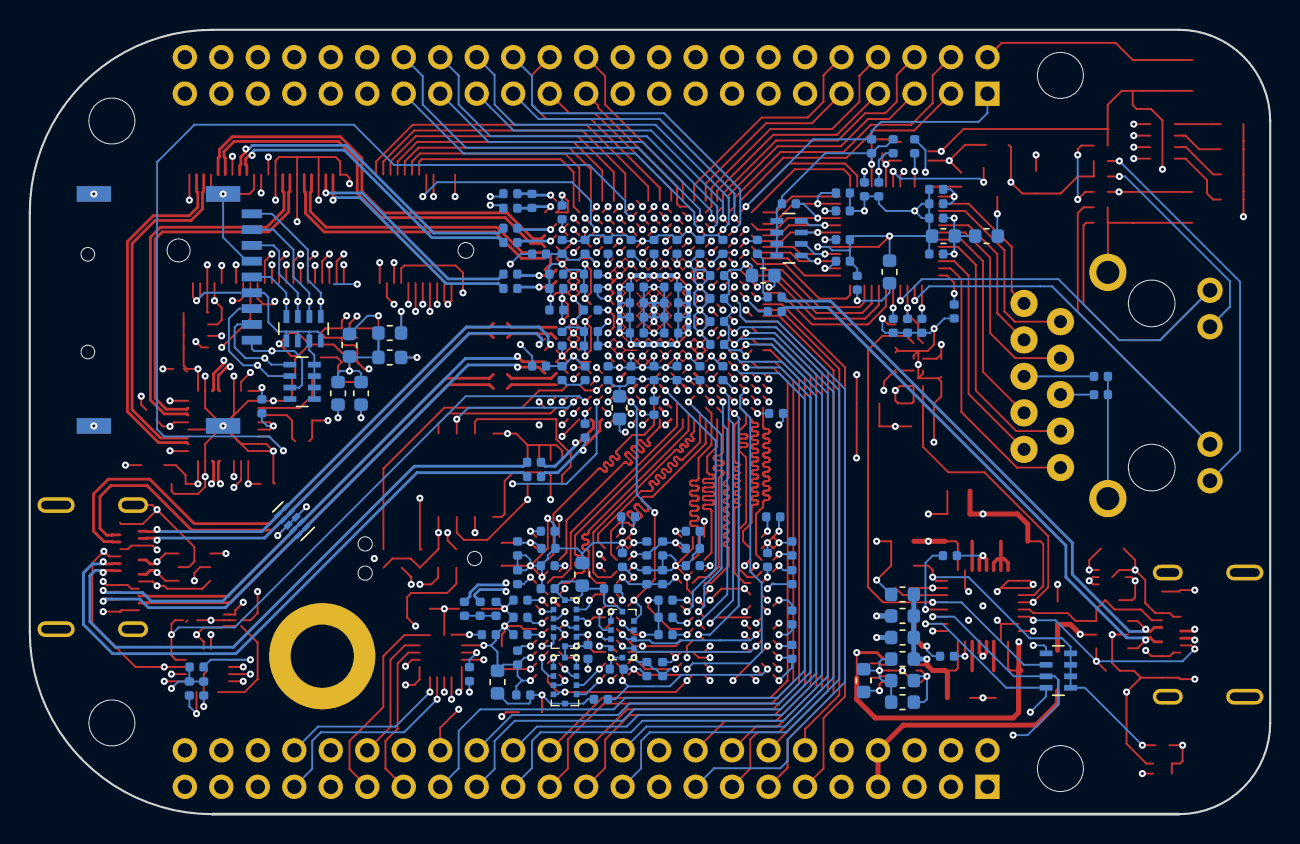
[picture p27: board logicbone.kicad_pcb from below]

Board: 8 copper layers, 86.4 x 54.6 mm, 255 parts (150 on the bottom side), 310 nets.

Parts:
C1, C108, C109: C_Small; C_0402_1005Metric
C2, C3, C8, C9, C10, C11, C110, C111, C112, C113, C114, C115, C116, C118, C120, C121, C122, C123, C201, C202, C210, C211, C221, C222, C230, C231, C257, C260, C261, C264, C265, C266, C280, C300, C301, C302, C309, C310, C311, C316, C317, C318, C319, C401, C402, C403, C411, C412, C421, C422, C423, C431, C432, C451, C452, C454, C455, C456, C461, C462, C463, C464, C465, C467, C469, C500, C501, C502, C504, C514, C517, C522, C527: 100nF; C_0402_1005Metric
C4, C258, C404, C405, C406, C414, C415, C416, C424, C425, C426, C434, C435, C436, C505, C506, C508, C509, C512, C513, C515, C516, C520, C521, C525, C526: 10nF; C_0402_1005Metric
C5, C100, C101, C102, C104, C117, C150, C151, C152, C154, C155, C156, C158, C159, C160, C161, C162, C163, C164, C165, C166, C167, C170, C171, C255, C303, C304, C308, C315, C400, C410, C420, C430, C440, C441, C442, C443, C445, C460, C524, C529: 10uF; C_0603_1608Metric
C6, C259, C305, C306, C307, C312, C313, C314: 1nF; C_0402_1005Metric
C7: 1uF; C_0603_1608Metric
D1: LED_Dual_ACAC; LED_0603_DUAL
D2, D3, D4, D5: LED_ALT; LED_0603_1608Metric
D6: D_Schottky_ALT; D_SOD-123F
D7, D8: D5V0F4U6SO; SOT-23-6
D9, D10: TPD4E02B04; USON-10_2.5x1.0mm_P0.5mm
FB1, FB2, FB3, FB4, FB5, FB7, FB8, FB9: MPZ1608S600; L_0603_1608Metric
H1, H2, H3, H4: MountingHole; MountingHole_3.2mm_M3
H5: MountingHole_Pad; wurth-9774025360
IC1: ECP5UM-CABGA381; caBGA-381_20x20_17.0x17.0mm
IC2, IC3: DDR3-TFBGA78; FBGA-78_7.5x11mm_Layout2x3x13_P0.8mm
IC4: MXL7704; QFN-32-1EP_5x5mm_P0.5mm_EP3.65x3.65mm
IC5: PI6CG18401; QFN-32-1EP_5x5mm_P0.5mm_EP3.1x3.1mm
IC6: NCP349; DFN6_1.6x2mm
IC7: FPF2595; WLCSP-12_3x4_1.3x1.8mm
IC8: FUSB307; UQFN-16-1EP_3x3mm_P0.5mm_EP1.75x1.75mm
IC9: TLA2518; WQFN-16-1EP_3x3mm_P0.5mm_EP1.75x1.75mm
IC10: AT25SL128A; DFN-8-1EP_6x5mm_P1.27mm_EP4x4mm
IC12: 74LVC1G07; SOT-353_SC-70-5
IC13: TPS51206; WSON-10EP-2x2mm
IC14: KSZ9031RNXCA; QFN-48-1EP_7x7mm_P0.5mm_EP5.15x5.15mm
IC17, IC18: NCP110AMX110; UDFN-4-1EP_1x1mm_P0.65mm_EP0.48x0.48mm
IC19, IC20: NCP115AMX250; UDFN-4-1EP_1x1mm_P0.65mm_EP0.48x0.48mm
J1: NGFF-KEY-E; TE-2199119-4
J2, J5: USB_C_Receptacle; Molex-1054500101
J3: ARJM11xx-502; ARJM11B1_502
J4: TC2050-IDC-NL; Tag-Connect_TC2050-IDC-NL_2x05_P1.27mm_Vertical
J6: Micro_SD_MEM2075; MEM2075
L1: 2.2uH; L_0805_2012Metric
L2, L4: 0.47uH; L_0805_2012Metric
L3: 1uH; L_0805_2012Metric
P8, P9: BB_2x23; PinHeader_2x23_P2.54mm_Vertical
Q1: Q_PMOS_GSD; SOT-23
R1, R2, R6, R37: 20; R_0402_1005Metric
R3, R4: 240; R_0402_1005Metric
R5: 100; R_0402_1005Metric
R7: 12.1k; R_0402_1005Metric
R8, R13, R18, R20, R21, R22, R23, R24, R25, R30, R31, R32, R35: 10k; R_0402_1005Metric
R9, R14, R15, R16: 47; R_0402_1005Metric
R10: 470; R_0402_1005Metric
R11, R12: 5.1k; R_0402_1005Metric
R17, R26: 1.5k; R_0402_1005Metric
R19, R29: 4.7k; R_0402_1005Metric
R27, R28: R; R_0402_1005Metric
R33: 750; R_0402_1005Metric
R34, R36: 1.2k; R_0402_1005Metric
RN1, RN2, RN3: 47; EXBD-1206
RN4, RN5, RN7: 4.7k; R_Array_Concave_4x0603
RN6, RN8, RN11: 10k; R_Array_Concave_4x0603
RN9: 470; R_Array_Concave_4x0603
SW1, SW2: SW_SPST; SW_SPST_PTS810
Y1: 25MHz; Crystal_SMD_2520-4Pin_2.5x2.0mm

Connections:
+3V3: C100.1, IC4.1, IC4.8, R10.2, R19.1, R29.1, RN5.5, RN5.6, RN5.7, RN5.8
/DDR3 Power/VDDR_CORE: C400.1, C401.1, C402.1, C403.1, C404.1, C405.1, C406.1, C420.1, C421.1, C422.1, C423.1, C424.1, C425.1, C426.1, FB9.2, IC2.A2, IC2.A9, IC2.D7, IC2.G2, IC2.G8, IC2.K1, IC2.K9, IC2.M1, IC2.M9, IC3.A2, IC3.A9, IC3.D7, IC3.G2, IC3.G8, IC3.K1, IC3.K9, IC3.M1, IC3.M9
/DDR3 Power/VDDR_IO: C410.1, C411.1, C412.1, C414.1, C415.1, C416.1, C430.1, C431.1, C432.1, C434.1, C435.1, C436.1, FB8.2, IC2.B9, IC2.C1, IC2.E2, IC2.E9, IC3.B9, IC3.C1, IC3.E2, IC3.E9
/Ethernet/25M_REFCLK: C2.1, IC1.M19, IC5.6
/Ethernet/ETH_1V2: C308.1, C309.1, C310.1, C311.1, C312.1, C313.1, C314.1, FB7.2, IC14.14, IC14.18, IC14.23, IC14.26, IC14.30, IC14.39, Q1.3
/Ethernet/ETH_AVDDL: C315.1, C316.1, C317.1, FB7.1, IC14.4, IC14.9, IC14.44
/Ethernet/ETH_LDO: IC14.43, Q1.1
/Ethernet/ETH_LED_L: IC14.15, J3.L2, R24.2
/Ethernet/ETH_LED_R: IC14.17, J3.L4, R25.2
/Ethernet/ETH_REFCLK: IC1.D12, IC14.41, R21.2, R22.2
/Ethernet/ETH_RXCLK: IC1.A18, IC14.35, R23.2
/Ethernet/ETH_RXCTL: IC1.B18, IC14.33, R20.2
/Ethernet/ETH_RXD0: IC1.A17, IC14.32, RN11.4
/Ethernet/ETH_RXD1: IC1.B17, IC14.31, RN11.3
/Ethernet/ETH_RXD2: IC1.A16, IC14.28, RN11.2
/Ethernet/ETH_RXD3: IC1.B16, IC14.27, RN11.1
/Ethernet/ETH_TRXD1N: IC14.3, J3.2
/Ethernet/ETH_TRXD1P: IC14.2, J3.1
/Ethernet/ETH_TRXD2N: IC14.6, J3.4
/Ethernet/ETH_TRXD2P: IC14.5, J3.3
/Ethernet/ETH_TRXD3N: IC14.8, J3.8
/Ethernet/ETH_TRXD3P: IC14.7, J3.7
/Ethernet/ETH_TRXD4N: IC14.11, J3.10
/Ethernet/ETH_TRXD4P: IC14.10, J3.9
/Ethernet/ETH_TXCLK: IC1.B15, IC14.24
/Ethernet/ETH_TXCTL: IC1.A15, IC14.25
/Ethernet/ETH_TXD0: IC1.A12, IC14.19
/Ethernet/ETH_TXD1: IC1.A13, IC14.20
/Ethernet/ETH_TXD2: IC1.C14, IC14.21
/Ethernet/ETH_TXD3: IC1.A14, IC14.22
/Ethernet/FPGA_USB+: D7.1, J2.A6, J2.B6, R1.1
/Ethernet/FPGA_USB-: D7.3, J2.A7, J2.B7, R2.1
/Ethernet/FPGA_USB_PULL: IC1.C16, R26.2
/Ethernet/LED_USER1: IC1.D16, J1.6, RN9.8
/Ethernet/LED_USER2: IC1.C15, J1.16, RN9.7
/Ethernet/LED_USER3: IC1.C13, RN9.6
/Ethernet/LED_USER4: IC1.B13, RN9.5
/Ethernet/MDIO_CLK: IC1.A19, IC14.36
/Ethernet/MDIO_DATA: IC1.B19, IC14.37
/Ethernet/MMC_CLK: IC1.E11, J6.5, RN6.4
/Ethernet/MMC_CMD: IC1.D15, J6.3, RN8.6
/Ethernet/MMC_DAT0: IC1.D13, J6.7, RN6.3
/Ethernet/MMC_DAT1: IC1.E13, J6.8, RN6.2
/Ethernet/MMC_DAT2: IC1.E15, J6.1, RN8.7
/Ethernet/MMC_DAT3: IC1.E14, J6.2, RN8.5
/Ethernet/MMC_DET: IC1.D14, J6.9, RN6.1
/Ethernet/~ETH_INT: IC1.B20, IC14.38
/Ethernet/~ETH_RESET: IC1.C17, IC12.4, IC14.42, R13.2
/Ethernet/~SYS_RESET: IC1.W3, IC12.2, J4.10, P9.10, R19.2, SW2.1
/Exp Headers/ADC_MISO: IC1.E8, IC9.12
/Exp Headers/ADC_MOSI: IC1.D10, IC9.14
/Exp Headers/ADC_SCLK: IC1.E9, IC9.13
/Exp Headers/P8_LVDS1n: IC1.D19, P8.4
/Exp Headers/P8_LVDS1p: IC1.C20, P8.3
/Exp Headers/P8_LVDS2n: IC1.E19, P8.6
/Exp Headers/P8_LVDS2p: IC1.D20, P8.5
/Exp Headers/P8_LVDS3n: IC1.F19, P8.8
/Exp Headers/P8_LVDS3p: IC1.E20, P8.7
/Exp Headers/P8_LVDS4n: IC1.G20, P8.10
/Exp Headers/P8_LVDS4p: IC1.F20, P8.9
/Exp Headers/P8_LVDS5n: IC1.H20, P8.24
/Exp Headers/P8_LVDS5p: IC1.G19, P8.23
/Exp Headers/P8_LVDS6n: IC1.K20, P8.26
/Exp Headers/P8_LVDS6p: IC1.J20, P8.25
/Exp Headers/P8_LVDS7n: IC1.D17, P8.28
/Exp Headers/P8_LVDS7p: IC1.C18, P8.27
/Exp Headers/P8_LVDS8n: IC1.E17, P8.30
/Exp Headers/P8_LVDS8p: IC1.D18, P8.29
/Exp Headers/P8_LVDS9n: IC1.F18, P8.32
/Exp Headers/P8_LVDS9p: IC1.E18, P8.31
/Exp Headers/P8_LVDS10n: IC1.G18, P8.34
/Exp Headers/P8_LVDS10p: IC1.F17, P8.33
/Exp Headers/P8_LVDS11n: IC1.F16, P8.36
/Exp Headers/P8_LVDS11p: IC1.E16, P8.35
/Exp Headers/P8_LVDS12n: IC1.H16, P8.38
/Exp Headers/P8_LVDS12p: IC1.G16, P8.37
/Exp Headers/P8_LVDS13n: IC1.J16, P8.40
/Exp Headers/P8_LVDS13p: IC1.J17, P8.39
/Exp Headers/P8_LVDS14n: IC1.H17, P8.42
/Exp Headers/P8_LVDS14p: IC1.H18, P8.41
/Exp Headers/P8_LVDS15n: IC1.K19, P8.44
/Exp Headers/P8_LVDS15p: IC1.J19, P8.43
/Exp Headers/P8_LVDS16n: IC1.K18, P8.46
/Exp Headers/P8_LVDS16p: IC1.J18, P8.45
/Exp Headers/P9_AIN0: IC9.15, P9.39
/Exp Headers/P9_AIN1: IC9.16, P9.40
/Exp Headers/P9_AIN2: IC9.1, P9.37
/Exp Headers/P9_AIN3: IC9.2, P9.38
/Exp Headers/P9_AIN4: IC9.3, P9.33
/Exp Headers/P9_AIN5: IC9.4, P9.36
/Exp Headers/P9_AIN6: IC9.5, P9.35
/Exp Headers/P9_CLKOUT: IC1.B10, P9.41
/Exp Headers/P9_GPIO11: IC1.A11, P9.11
/Exp Headers/P9_GPIO12: IC1.B11, P9.12
/Exp Headers/P9_GPIO13: IC1.A10, P9.13
/Exp Headers/P9_GPIO14: IC1.C10, P9.14
/Exp Headers/P9_GPIO15: IC1.A9, P9.15
/Exp Headers/P9_GPIO16: IC1.B9, P9.16
/Exp Headers/P9_GPIO17: IC1.C11, P9.17
/Exp Headers/P9_GPIO18: IC1.A8, P9.18
/Exp Headers/P9_GPIO21: IC1.D9, P9.21
/Exp Headers/P9_GPIO22: IC1.C8, P9.22
/Exp Headers/P9_GPIO23: IC1.B8, P9.23
/Exp Headers/P9_GPIO24: IC1.A7, P9.24
/Exp Headers/P9_GPIO25: IC1.A6, P9.25
/Exp Headers/P9_GPIO26: IC1.B6, P9.26
/Exp Headers/P9_GPIO27: IC1.D8, P9.27
/Exp Headers/P9_GPIO42: IC1.E10, P9.42
/Exp Headers/P9_SPI_D0: IC1.D7, P9.29
/Exp Headers/P9_SPI_D1: IC1.C6, P9.30
/Exp Headers/P9_SPI_SCLK: IC1.D6, P9.31
/Exp Headers/PWR_BUTTON: IC1.U2, P9.9, R29.2, SW1.1
/Exp Headers/SCL: IC1.U1, IC4.3, IC5.10, IC8.12, J1.60, P9.19, RN5.3
/Exp Headers/SDA: IC1.V1, IC4.2, IC5.11, IC8.11, J1.58, P9.20, RN5.4
/Exp Headers/SYS_5V: D6.1, P9.7, P9.8
/Exp Headers/~ADC_CSEL: IC1.E6, IC9.11
/Exp Headers/~P9_SPI_CSEL: IC1.C7, P9.28
/FPGA Memory/DDR3_A0: IC1.B4, IC2.K3, IC3.K3, RN3.3
/FPGA Memory/DDR3_A1: IC1.F4, IC2.L7, IC3.L7, RN2.2
/FPGA Memory/DDR3_A2: IC1.A4, IC2.L3, IC3.L3, RN1.9
/FPGA Memory/DDR3_A3: IC1.F3, IC2.K2, IC3.K2, RN3.9
/FPGA Memory/DDR3_A4: IC1.E5, IC2.L8, IC3.L8, RN2.8
/FPGA Memory/DDR3_A5: IC1.C5, IC2.L2, IC3.L2, RN3.2
/FPGA Memory/DDR3_A6: IC1.C4, IC2.M8, IC3.M8, RN2.9
/FPGA Memory/DDR3_A7: IC1.A5, IC2.M2, IC3.M2, R14.2
/FPGA Memory/DDR3_A8: IC1.A3, IC2.N8, IC3.N8, RN2.6
/FPGA Memory/DDR3_A9: IC1.B5, IC2.M3, IC3.M3, RN2.4
/FPGA Memory/DDR3_A10: IC1.G3, IC2.H7, IC3.H7, RN1.4
/FPGA Memory/DDR3_A11: IC1.D5, IC2.M7, IC3.M7, RN2.3
/FPGA Memory/DDR3_A12: IC1.D2, IC2.K7, IC3.K7, RN1.3
/FPGA Memory/DDR3_A13: IC1.F5, IC2.N3, IC3.N3, RN2.5
/FPGA Memory/DDR3_A14: IC1.D3, IC2.N7, IC3.N7, RN2.7
/FPGA Memory/DDR3_A15: IC1.E3, IC2.J7, IC3.J7, RN1.8
/FPGA Memory/DDR3_BA0: IC1.B3, IC2.J2, IC3.J2, RN3.8
/FPGA Memory/DDR3_BA1: IC1.H5, IC2.K8, IC3.K8, RN1.2
/FPGA Memory/DDR3_BA2: IC1.N2, IC2.J3, IC3.J3, RN3.5
/FPGA Memory/DDR3_CK+: IC1.M4, IC2.F7, IC3.F7, R15.2
/FPGA Memory/DDR3_CK-: IC1.N5, IC2.G7, IC3.G7, R16.1
/FPGA Memory/DDR3_CKE: IC1.K4, IC2.G9, IC3.G9, RN1.5
/FPGA Memory/DDR3_DM0: IC1.L4, IC2.A7
/FPGA Memory/DDR3_DM1: IC1.J5, IC3.A7
/FPGA Memory/DDR3_DQ0: IC1.G2, IC2.B3
/FPGA Memory/DDR3_DQ1: IC1.K1, IC2.C7
/FPGA Memory/DDR3_DQ2: IC1.F1, IC2.C2
/FPGA Memory/DDR3_DQ3: IC1.K3, IC2.C8
/FPGA Memory/DDR3_DQ4: IC1.H2, IC2.E3
/FPGA Memory/DDR3_DQ5: IC1.J3, IC2.E8
/FPGA Memory/DDR3_DQ6: IC1.G1, IC2.D2
/FPGA Memory/DDR3_DQ7: IC1.H1, IC2.E7
/FPGA Memory/DDR3_DQ8: IC1.B1, IC3.B3
/FPGA Memory/DDR3_DQ9: IC1.E1, IC3.C7
/FPGA Memory/DDR3_DQ10: IC1.A2, IC3.C2
/FPGA Memory/DDR3_DQ11: IC1.F2, IC3.C8
/FPGA Memory/DDR3_DQ12: IC1.C1, IC3.E3
/FPGA Memory/DDR3_DQ13: IC1.E2, IC3.E8
/FPGA Memory/DDR3_DQ14: IC1.C2, IC3.D2
/FPGA Memory/DDR3_DQ15: IC1.D1, IC3.E7
/FPGA Memory/DDR3_DQS0+: IC1.K2, IC2.C3
/FPGA Memory/DDR3_DQS0-: IC1.J1, IC2.D3
/FPGA Memory/DDR3_DQS1+: IC1.H4, IC3.C3
/FPGA Memory/DDR3_DQS1-: IC1.G5, IC3.D3
/FPGA Memory/DDR3_ODT0: IC1.N3, IC2.G1, RN3.6
/FPGA Memory/DDR3_ODT1: IC1.C3, IC3.G1, R9.1
/FPGA Memory/DDR3_VREF: C460.1, C461.1, C462.2, C463.1, C464.1, C465.1, C467.1, IC1.B2, IC1.K5, IC2.E1, IC2.J8, IC3.E1, IC3.J8, IC13.6
/FPGA Memory/~DDR3_CAS: IC1.M1, IC2.G3, IC3.G3, RN3.4
/FPGA Memory/~DDR3_CS: IC1.M3, IC2.H2, IC3.H2, RN3.7
/FPGA Memory/~DDR3_RAS: IC1.L1, IC2.F3, IC3.F3, RN1.6
/FPGA Memory/~DDR3_RST: IC1.P1, IC2.N2, IC3.N2
/FPGA Memory/~DDR3_WE: IC1.E4, IC2.H3, IC3.H3, RN1.7
/FPGA Power/PGOOD: D1.1, D1.3, IC4.20, IC20.3, R10.1, RN5.1
/FPGA Power/PMIC_ENABLE: IC4.6, R32.1
/FPGA Power/PMIC_PG1: IC4.5, IC19.3, RN5.2
/FPGA Power/PMIC_SEQ: IC4.4, R18.2
/FPGA Power/USB_UFP_CC1: D7.6, IC4.21, J2.A5, R12.2
/FPGA Power/USB_UFP_CC2: D7.4, IC4.22, J2.B5, R11.1
/FPGA Power/VCCA0: C520.1, C521.1, C522.1, C524.1, FB2.2, IC1.T6, IC1.U6
/FPGA Power/VCCA1: C525.1, C526.1, C527.1, C529.1, FB3.2, IC1.T15, IC1.U15
/FPGA SERDES/FPGA_REFCLK+: IC1.P3, IC5.13
/FPGA SERDES/FPGA_REFCLK-: IC1.P4, IC5.14
/FPGA SERDES/M2_COEX1: IC1.P18, J1.44
/FPGA SERDES/M2_COEX2: IC1.P19, J1.46
/FPGA SERDES/M2_COEX3: IC1.N17, J1.48
/FPGA SERDES/M2_CTS: IC1.R18, J1.34
/FPGA SERDES/M2_PCM_CLK: IC1.U16, J1.8
/FPGA SERDES/M2_PCM_IN: IC1.P16, J1.12
/FPGA SERDES/M2_PCM_OUT: IC1.T16, J1.14
/FPGA SERDES/M2_PCM_SYNC: IC1.N16, J1.10
/FPGA SERDES/M2_RTS: IC1.U18, J1.36
/FPGA SERDES/M2_RXD: IC1.R17, J1.22
/FPGA SERDES/M2_SDIO_CLK: IC1.T17, J1.9
/FPGA SERDES/M2_SDIO_CMD: IC1.U19, J1.11
/FPGA SERDES/M2_SDIO_DATA0: IC1.U20, J1.13
/FPGA SERDES/M2_SDIO_DATA1: IC1.T20, J1.15
/FPGA SERDES/M2_SDIO_DATA2: IC1.R20, J1.17
/FPGA SERDES/M2_SDIO_DATA3: IC1.P20, J1.19
/FPGA SERDES/M2_SUSCLK: IC1.L16, J1.50
/FPGA SERDES/M2_TXD: IC1.U17, J1.32
/FPGA SERDES/M2_VEND0: IC1.N18, J1.42
/FPGA SERDES/M2_VEND1: IC1.T19, J1.40
/FPGA SERDES/M2_VEND2: IC1.P17, J1.38
/FPGA SERDES/PCIE_REFCLK0+: IC5.23, J1.47
/FPGA SERDES/PCIE_REFCLK0-: IC5.22, J1.49
/FPGA SERDES/PCIE_REFCLK1+: IC5.19, J1.71
/FPGA SERDES/PCIE_REFCLK1-: IC5.18, J1.73
/FPGA SERDES/PCIE_RX0+: IC1.Y14, J1.41
/FPGA SERDES/PCIE_RX0-: IC1.Y15, J1.43
/FPGA SERDES/PCIE_RX1+: IC1.Y16, J1.65
/FPGA SERDES/PCIE_RX1-: IC1.Y17, J1.67
/FPGA SERDES/PCIE_TX0+: C115.2, J1.35
/FPGA SERDES/PCIE_TX0-: C114.2, J1.37
/FPGA SERDES/PCIE_TX1+: C113.2, J1.59
/FPGA SERDES/PCIE_TX1-: C112.2, J1.61
/FPGA SERDES/SERDES_REFCLK+: C111.2, IC5.28
/FPGA SERDES/SERDES_REFCLK-: C110.2, IC5.27
/FPGA SERDES/VCCTRX1: C255.1, C257.1, C258.1, C259.1, FB5.1, IC1.T11, IC1.T12, IC1.T13, IC1.T14
/FPGA SERDES/~M2_ALERT: IC1.L19, J1.62
/FPGA SERDES/~M2_SDIO_RESET: IC1.L20, J1.23
/FPGA SERDES/~M2_SDIO_WAKE: IC1.N20, J1.21
/FPGA SERDES/~M2_UART_WAKE: IC1.T18, J1.20
/FPGA SERDES/~M2_WDIS1: IC1.L17, J1.56
/FPGA SERDES/~M2_WDIS2: IC1.M18, J1.54
/FPGA SERDES/~PCIE_CLKREQ0: IC5.24, J1.53, RN4.4
/FPGA SERDES/~PCIE_CLKREQ1: IC5.17, J1.68, RN4.2
/FPGA SERDES/~PCIE_RESET0: IC1.M17, J1.52
/FPGA SERDES/~PCIE_RESET1: IC1.N19, J1.66
/FPGA SERDES/~PCIE_WAKE0: IC1.L18, J1.55, RN4.3
/FPGA SERDES/~PCIE_WAKE1: IC1.M20, J1.70, RN4.1
/USB and Programming/DFP_SOURCE_EN: IC7.D3, IC8.13
/USB and Programming/FLASH_D2: IC1.Y2, IC10.3, RN7.4
/USB and Programming/FLASH_D3: IC1.W1, IC10.7, RN7.1
/USB and Programming/FLASH_MISO: IC1.V2, IC10.2
/USB and Programming/FLASH_MOSI: IC1.W2, IC10.5
/USB and Programming/FLASH_SCLK: IC1.U3, IC10.6
/USB and Programming/FPGA_TCK: IC1.T5, J4.4
/USB and Programming/FPGA_TDI: IC1.R5, J4.8
/USB and Programming/FPGA_TDO: IC1.V4, J4.6
/USB and Programming/FPGA_TMS: IC1.U5, J4.2
/USB and Programming/FPGA_USB_DFP+: IC1.R1, R6.1, R17.2
/USB and Programming/FPGA_USB_DFP-: IC1.T1, R37.2
/USB and Programming/USBC_DFP+: D8.1, J5.A6, J5.B6, R6.2
/USB and Programming/USBC_DFP-: D8.3, J5.A7, J5.B7, R37.1
/USB and Programming/USBSS_RX1+: D10.1, D10.10, IC1.Y5, J5.B11
/USB and Programming/USBSS_RX1-: D10.2, D10.9, IC1.Y6, J5.B10
/USB and Programming/USBSS_RX2+: D10.5, D10.6, IC1.Y7, J5.A11
/USB and Programming/USBSS_RX2-: D10.4, D10.7, IC1.Y8, J5.A10
/USB and Programming/USBSS_TX1+: C8.2, D9.5, D9.6, J5.A2
/USB and Programming/USBSS_TX1-: C9.2, D9.4, D9.7, J5.A3
/USB and Programming/USBSS_TX2+: C10.2, D9.2, D9.9, J5.B2
/USB and Programming/USBSS_TX2-: C11.2, D9.1, D9.10, J5.B3
/USB and Programming/USB_DFP_CC1: D8.6, IC8.1, J5.A5
/USB and Programming/USB_DFP_CC2: D8.4, IC8.3, J5.B5
/USB and Programming/USB_DFP_PULL: IC1.T2, R17.1
/USB and Programming/USB_DFP_VBUS: IC7.A3, IC7.B3, IC7.C3, IC8.6, J5.A4, J5.A9, J5.B4, J5.B9
/USB and Programming/USB_ORIENT: IC1.T3, IC8.4, R35.2
/USB and Programming/VCCTRX0: C3.1, C4.1, C5.1, C6.1, FB4.1, IC1.T7, IC1.T8, IC1.T9, IC1.T10
/USB and Programming/~FLASH_CSEL: IC1.R2, IC10.1, RN7.2
/USB and Programming/~FPGA_INIT: D1.4, IC1.V3
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

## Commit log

2019-12-14 Add ECP5UM-CABGA381 schematic symbol.
    [fpga-io.sch, fpga-memory.sch, fpga-power.sch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]
2019-12-28 Add major schematic components.
    This adds the bulk of the components to the schematic and performs an
    initial routing of signals to the FPGA, PMIC and Supervisor. This is
    still missing most, if not all, bypass capacitors.
    [ethernet.sch, exp-headers.sch, fpga-io.sch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]
2020-01-05 Finalize SERDES, exp headers, and start footprint association.
    [c-2199119-4-c-3d.stp, ddr3-power.sch, ethernet.sch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]
2020-01-13 Initial board outline and component placement.
    [arjm11b1-502.fcstd, arjm11b1-502.step, ethernet.sch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]
2020-01-20 Revert back to a 16-bit DDR3 bus, initial DDR3 layout.
    The caBGA-554 package was too large and fat to reasonably be able
    to fit within the beaglebone footprint and still leave enough room
    for DDR3 and the expansion headers. So, it seems more sensible to
    switch back to a 16-bit wide bus.
    Now that we can fit everything, take a first stab at getting the DDR3
    data busses routed and length matched.
    [cabga-381-ecp5.step, ddr3-power.sch, ethernet.sch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]
2020-02-02 Complete routing of the DDR interface.
    This is the last of the DDR3 signals connected, but we still need to
    revisit the length tuning.
    [fpga-memory.sch, logicbone.kicad_pcb]
2020-02-08 More routing progress on Ethernet and DDR.
    [PTS810.step, ethernet.sch, exp-headers.sch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]
2020-03-05 Routing of M.2 and PCIe, placed the Supervisor.
    Started work on getting the power supplies layed out too, and spent
    some time thinking about how the USB-C should connect up to the FPGA.
    [ethernet.sch, exp-headers.sch, fpga-memory.sch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]
2020-04-16 Replace PMIC with MXL7704, switch to SPI master programming.
    The Quorvo PMIC in the original design appears to have been deprecated
    on DigiKey. Out of concern for availability, let's switch to the MXL7704
    instead.
    In an effort to support to an FPGA-based bootloader solution, we have
    switched to using SPI master mode for the ECP5 configuration data. In
    the long run this might allow a considerable downsizing of the STM32.
    [WSON10-2x2mm-EP.step, ddr3-power.sch, ethernet.sch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]
2020-04-18 Add dedicated LDO for VCCAUX, and a bunch of cleanup
    The MXL7704 is almost capable of booting the entire ECP5 on its own
    without any help from the supervisor. So we would like to test it out
    on the prototype boards. To accompish this, we need to use a dedicated
    LDO for VCCAUX.
    With that, I am rapidly running out of major work to do and from here
    on out it's just going to be review and minor tweaks.
    [bb-pin-header-2x23.FCStd, bb-pin-header-2x23.step, ethernet.sch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]
2020-04-19 Place VTT bypass caps, revisit DDR length matching.
    [ddr3-power.sch, ethernet.sch, exp-headers.sch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]
2020-04-19 Add power fill zones for VCORE and DDR3 voltages.
    [ddr3-power.sch, ethernet.sch, exp-headers.sch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]
2020-04-20 Move +3V3 supply onto PMIC LDO.
    The default configuration of the MXL7704 allows the LDO to be used
    as an always-on supply by controlling the power-on using SEQ_EN in
    place of GLOBAL_EN. Doing so allows us to elminiate another
    regulator.
    [exp-headers.sch, fpga-power.sch, logicbone.kicad_pcb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]
2020-04-22 Remove STM32 and plan to use an FPGA bootloader instead.
    The MXL7704 is close enough to what the ECP5 needs that we can let
    it boot itself from the OTP and then fixup the voltages once the
    FPGA bootloader starts (the OTP is correct for the ECP5-5G).
    [ddr3-power.sch, ethernet.sch, exp-headers.sch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]
2020-04-25 Add a second USB-C port for USB host and SERDES breakout.
    Now that the supervisor is gone, we have a bunch more PCB space which
    we can use to add a USB-C downstream facing port that can serve as a
    USB host and to breakout the extra SERDES channels.
    [1054500101.stp, ddr3-power.sch, ethernet.sch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]
2020-04-26 Replace ADC with a TLA2518
    The previous ADC (STMicor ADC120) was only available in a TSSOP
    package, which was unfortunately too tall to clear a double-sided
    M.2 adaptor card. The TLA2518 comes in a WQFN16 package which is
    much shorter.
    [ethernet.sch, exp-headers.sch, fpga-serdes.sch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]
2020-04-29 Review BGA pinouts and differential pair tuning. Replace ADC.
    After double-checking the ECP5 pinout, there were a few minor pins that
    got swapped, but nothing that would have damaged anything. We also took
    the time to review the differential pair tuning, and we found that the
    ADC was too tall to clear the M.2 connector.
    Closes: https://github.com/oskirby/logicbone/issues/1
    [ddr3-power.sch, ethernet.sch, exp-headers.sch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]
2020-04-29 Tidy up silkscreen, add voltage test points
    [arjm11b1-502.step, ethernet.sch, exp-headers.sch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]
2020-05-01 Rev0 release to manufacturing.
    [arjm11b1-502.fcstd, ddr3-power.sch, ethernet.sch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]
2020-05-01 Update m.2 3d model to TE-2199230-4.
    It's the same footprint and everything, but with the correct Z-height
    to allow for PCB components on the mainboard.
    [c-2199230-4-b2-3d.stp, fpga-serdes.sch]
2020-05-01 Add missing 3D models for crystal and OVP protection.
    [dfn6-2x1.6mm.step]
2020-05-02 Rev0 release to manufacturing (again), due to DDR3 tuning.
    After doing some more review, it turns out that the DDR3 was not
    correctly length matched on the control and address bus. So lets try
    to squeak in a revision that fixes the DDR3 length matching. As a
    side effect, a handful of the pins got swapped around, and the ODT0
    and ODT1 signals got merged.
    [ddr3-tuning.ods, fpga-memory.sch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]
2020-05-02 Update DDR3 timing calculations.
    I forgot to check the updated spreadsheet in after the last few tweaks
    to the DDR3 length matching on the PCB.
    [ddr3-tuning.ods]
2020-05-03 Add BOM, with pricing and links for prototype run.
    For the prototype run, we would like to get two variants of the board
    populated. One with 512MB of RAM and the LFE5UM-45F FPGA, and then a
    souped up version with 2GB of RAM and the LFE5UM5G-85F FPGA.
    [logicbone-bom.ods]
2020-05-04 Tweak BOM to use ECP5-5G for all variants.
    The price difference between the LFE5UM-45F and the LFE5UM5G-45F is
    only a few dollars, and enables the user to play with USB Superspeed
    and PCIe 2.0, so this just seems like an obvious upgrade. We also
    increase the choice of RAM for the base model to 1GB.
    This also leads to a couple of tweaks in the LDO selection to switch
    the core and SERDES voltages from 1.1V to 1.2V for the 5G models.
    [ddr3-power.sch, ethernet.sch, exp-headers.sch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]
2020-06-01 Fix footprint attributes (through hole vs. SMD).
    The footprint attributes determine which parts are exported with the
    position data, which means that several components were missing from
    the last manufacturing package (IC1/2/3, D1, IC6, IC13, J1 and J2).
    This update should set the SMD attributes correctly.
    [logicbone-bom.ods]
2020-06-27 Add CERN OHL required documentation, annotate schematic.
    The CERN OHL requires the inclusion of a CHANGES.md and a PRODUCT.txt
    file to denote the change history of the project and the contact person
    for production information. While we're at it, we also try to imrpove
    the state of the schematic with explicit copyright and authorship notices
    plus some of the bodges that were added during prototype bringup.
    [ddr3-power.sch, ethernet.sch, exp-headers.sch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]
